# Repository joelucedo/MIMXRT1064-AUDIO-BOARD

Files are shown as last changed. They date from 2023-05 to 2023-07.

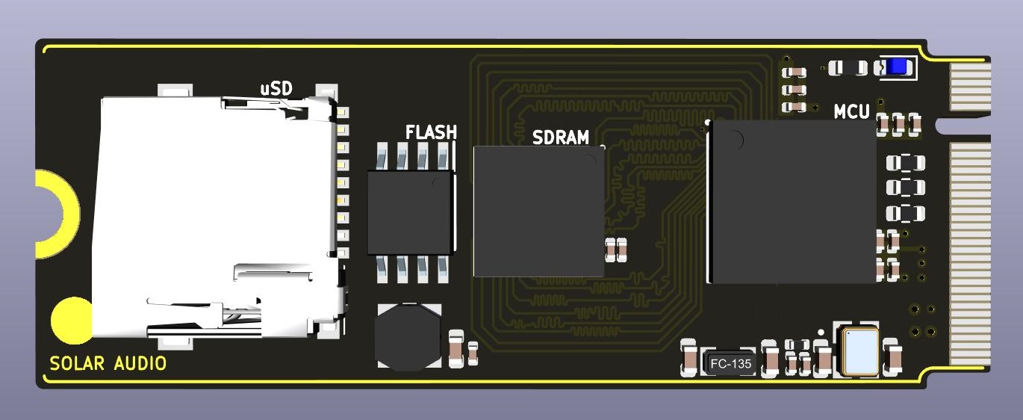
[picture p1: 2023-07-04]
IMAGES/MIMXRT1064 MCU Module.jpg

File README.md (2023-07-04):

# MIMXRT1064 MCU BOARD
MIMXRT1064 MCU Module

## WHAT ?
M7 MCU + SDRAM + FLASH + SD
</br>
## STATUS
Work in progress.
</br>
## SPECS
#### MCU : MIMXRT1064CVL5B 
* ***Cores*** : 1 x ARM Cortex M7 (32KB L1 Cache - FPU)
* ***Clock frequency*** : 528 MHz  
* ***On chip Flash*** : 4MB  
* ***On chip RAM*** : 1MB
* ***USB*** : Two USB 2.0 HS OTG controllers with integrated PHY interfaces
#### SDRAM : IS42S16160J-6BLI
* ***Memory Size*** : 256Mb
* ***Data Bus Width*** : 16 Bit
* ***Maximum clock frequency*** : 166MHz
#### QSPI Flash : IS25WP064A-JBLE
* ***Memory Size*** : 64Mbit
* ***Data Bus Width*** : 8 Bit
* ***Maximum clock frequency*** : 133MHz
#### SD Memory Card Socket
* ***Capacity*** : Up to 2TB SDHX card
* ***Data transfer rate*** : Up to 104 MB/s (UHS-I SDR104)

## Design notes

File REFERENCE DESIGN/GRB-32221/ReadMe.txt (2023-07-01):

README for GRB-32221_A1.zip

Company Part Number: 170-32221 REV A1

Date: Mon, 11 Mar 2019 02:16:21 GMT

NXP Semiconductors
6501 William Cannon Drive West
Austin, TX 78735-8598

CAD Engineer
============
Company Contact     : [full_name]
Work Phone          : 512-895-XXXX
Email               : [email]@nxp.com

CAD Manager
===========
Company Contact     : Daniel Kruczek
Work Phone          : 512-895-6081
Email               : daniel.kruczek@nxp.com

Manufacturing Program Manager
=============================
Company Contact     : [full_name]
Work Phone          : 512-895-XXXX
Email               : [email]@nxp.com

Product Engineer
================
Company Contact     : [full_name]
Work Phone          : 512-895-XXXX
Email               : [email]@nxp.com

Design for Manufacturing Engineer
=================================
Company Contact     : Andres Marquez
Work Phone          : +52(33) 3283-2100 x3068
Email               : andres.marquez@nxp.com

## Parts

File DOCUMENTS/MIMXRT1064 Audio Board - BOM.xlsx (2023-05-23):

MIMXRT1064 MCU Module - BOM
Ref | Description | Package/Mounting | Value | Quantity | Manufacturer | Manufacturer PN | Supplier | Supplier PN | Cost/Unit | Cost/Units | Stock | Basic/Extended | Notes
RESISTORS
 | SMD Chip Resistor - 10k - 62.5mW - ±1% - 0402 | 0402 | 10k |  | UNI-ROYAL | 0402WGF1002TCE | JLCPCB | C25744 | $0.0006 |  | 7272300 | Basic
 | SMD Chip Resistor - 30k - 62.5mW - ±1% - 0402 | 0402 | 30k |  | YAGEO | AF0402FR-0730KL | JLCPCB | C144036 | $0.004 |  | 9800 | Extended
 | SMD Chip Resistor - 2,2M - 62.5mW - ±1% - 0402 | 0402 | 2,2M |  | UNI-ROYAL | 0402WGJ0225TCE | JLCPCB | C26089 | $0.0005 |  | 10394 | Extended
CAPACITORS
 | SMD MLCC - 8pF - 50V - C0G - 0.5pF - 0402 | 0402 | 8pF |  | Murata Electronics | GCM1555C1H8R0DA16D | JLCPCB | C126517 | $0.0082 |  | 10225 | Extended
 | SMD MLCC - 12pF - 50V - C0G - ±2% - 0402 | 0402 | 12pF |  | Murata Electronics | GRM1555C1H120GA01D | JLCPCB | C161527 | $0.0092 |  | 6768 | Extended
 | SMD MLCC - 100nF - 50V - X7R - ±10% - 0402 | 0402 | 100nF |  | Samsung Electro-Mechanics | CL05B104KB54PNC | JLCPCB | C307331 | $0.0068 |  | 1466168 | Basic
 | SMD MLCC - 220nF - 16V - X7R - ±10% - 0402 | 0402 | 0.22uF |  | Samsung Electro-Mechanics | CL05B224KO5NNNC | JLCPCB | C16772 | $0.0051 |  | 120532 | Basic
 | SMD MLCC - 1uF - 25V - X5R - ±10% - 0402 | 0402 | 1uF |  | Samsung Electro-Mechanics | CL05A105KA5NQNC | JLCPCB | C52923 | $0.0039 |  | 1161993 | Basic
 | SMD MLCC - 4.7uF - 10V - X5R - ±20% - 0402 | 0402 | 4.7uF |  | Samsung Electro-Mechanics | CL05A475MP5NRNC | JLCPCB | C23733 | $0.0071 |  | 472642 | Basic
 | SMD MLCC -10uF - 10V - X5R - ±10% - 0603 | 0603 | 10uF |  | Samsung Electro-Mechanics | CL10A106KP8NNNC | JLCPCB | C19702 | $0.0066 |  | 1119998 | Basic
 | SMD MLCC - 22uF - 6.3V - X5R - ±20% -0603 | 0603 | 22uF |  | Samsung Electro-Mechanics | CL10A226MQ8NRNC | JLCPCB | C59461 | $0.0086 |  | 1692113 | Basic
INDUCTORS
 | SMD power inductor - 4.7uH - 800mA - 0R230 -20% - 0805 | 0805 | 4.7uH |  | Murata Electronics | LQM21PN4R7MGRD | JLCPCB | C86090 | $0.0765 |  | 4343 | Extended
FERRITE BEAD
 | SMD Ferrite - 120R - 800mA - 0.180R - 25% - SMD 0603 | 0603 | 120R@100MHz |  | Murata Electronics | BLM18AG121SN1D | JLCPCB | C76892 | $0.0084 |  | 78897 | Extended
INTEGRATED CIRCUITS
 | Microcontrôleurs ARM - MCU i.MXRT1064 | MAPBGA-196 |  |  | NXP Semicon | MIMXRT1064CVL5B | JLCPCB | C2879860 | $11.3056 |  | 942 | Extended
 | DRAM 256M, 3.3V, SDRAM, 16Mx16, 166Mhz, 54 ball BGA (8mmx8mm) | TFBGA-54(8x8) | 256Mbit (32MByte) |  | ISSI | IS42S16160J-6BLI | JLCPCB | C1351289 | $4.3646 |  | 280 | Extended
 | Flash NOR 64Mb QPI/QPI/QSPI, 8-pin SOP 208Mil | SOIC-Wide-8 | 64 Mbit |  | ISSI | IS25WP064A-JBLE | JLCPCB | C190624 | $1.0281 |  | 2304 | Extended
CRYSTALS
 | Crystal - 24MHz - 12pF - 40R - SMD2016-4P | SMD3225-4P | 24MHz |  | TXC Corp | 7V24000026 | JLCPCB | C337205 | $0.1455 |  | 2955 | Extended
 | Crystal - 32.768kHz - 7pF - 70k - ±20ppm - SMD3215-2P | SMD3215-2P | 32.768 MHz |  | Seiko Epson | Q13FC1350000200 | JLCPCB | C48615 | $0.2144 |  | 1441 | Extended
MECHANICALS
 | Deck MicroSD card (TF card) Self bomb SMD SD Card Connectors |  |  |  | SOFNG | TF-15x15 | JLCPCB | C111196 | $0.1986 |  | 4957 | Extended

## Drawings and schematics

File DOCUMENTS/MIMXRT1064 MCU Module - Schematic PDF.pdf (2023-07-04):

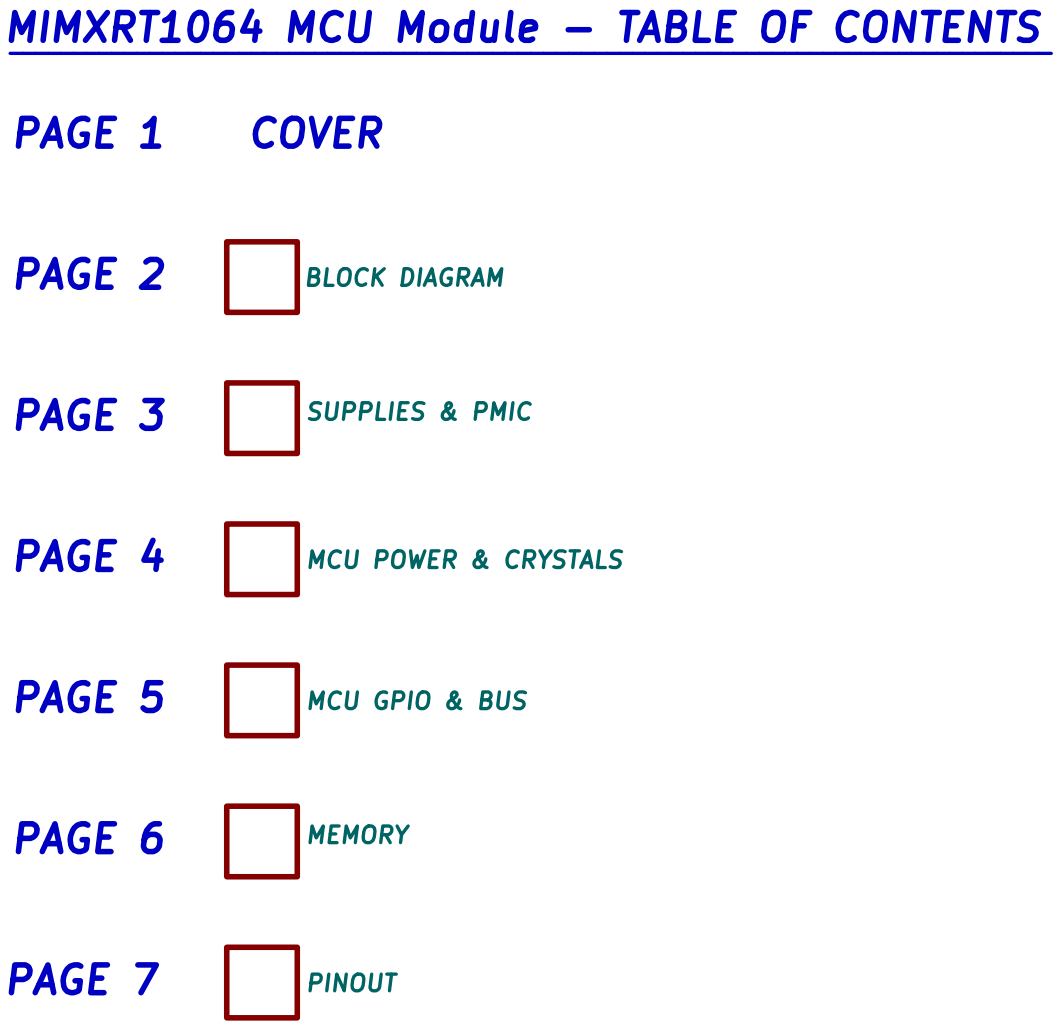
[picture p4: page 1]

MIMXRT1064 MCU Module - TABLE OF CONTENTS
__________________________________________________________________________________ PAGE 6
PAGE 1 COVER

File: MIMXRT1064 MCU Module.kicad_sch Sheet: / þÿJoël Ucedo

Id: 1/7 Title: MIMXRT1064 MCU Module

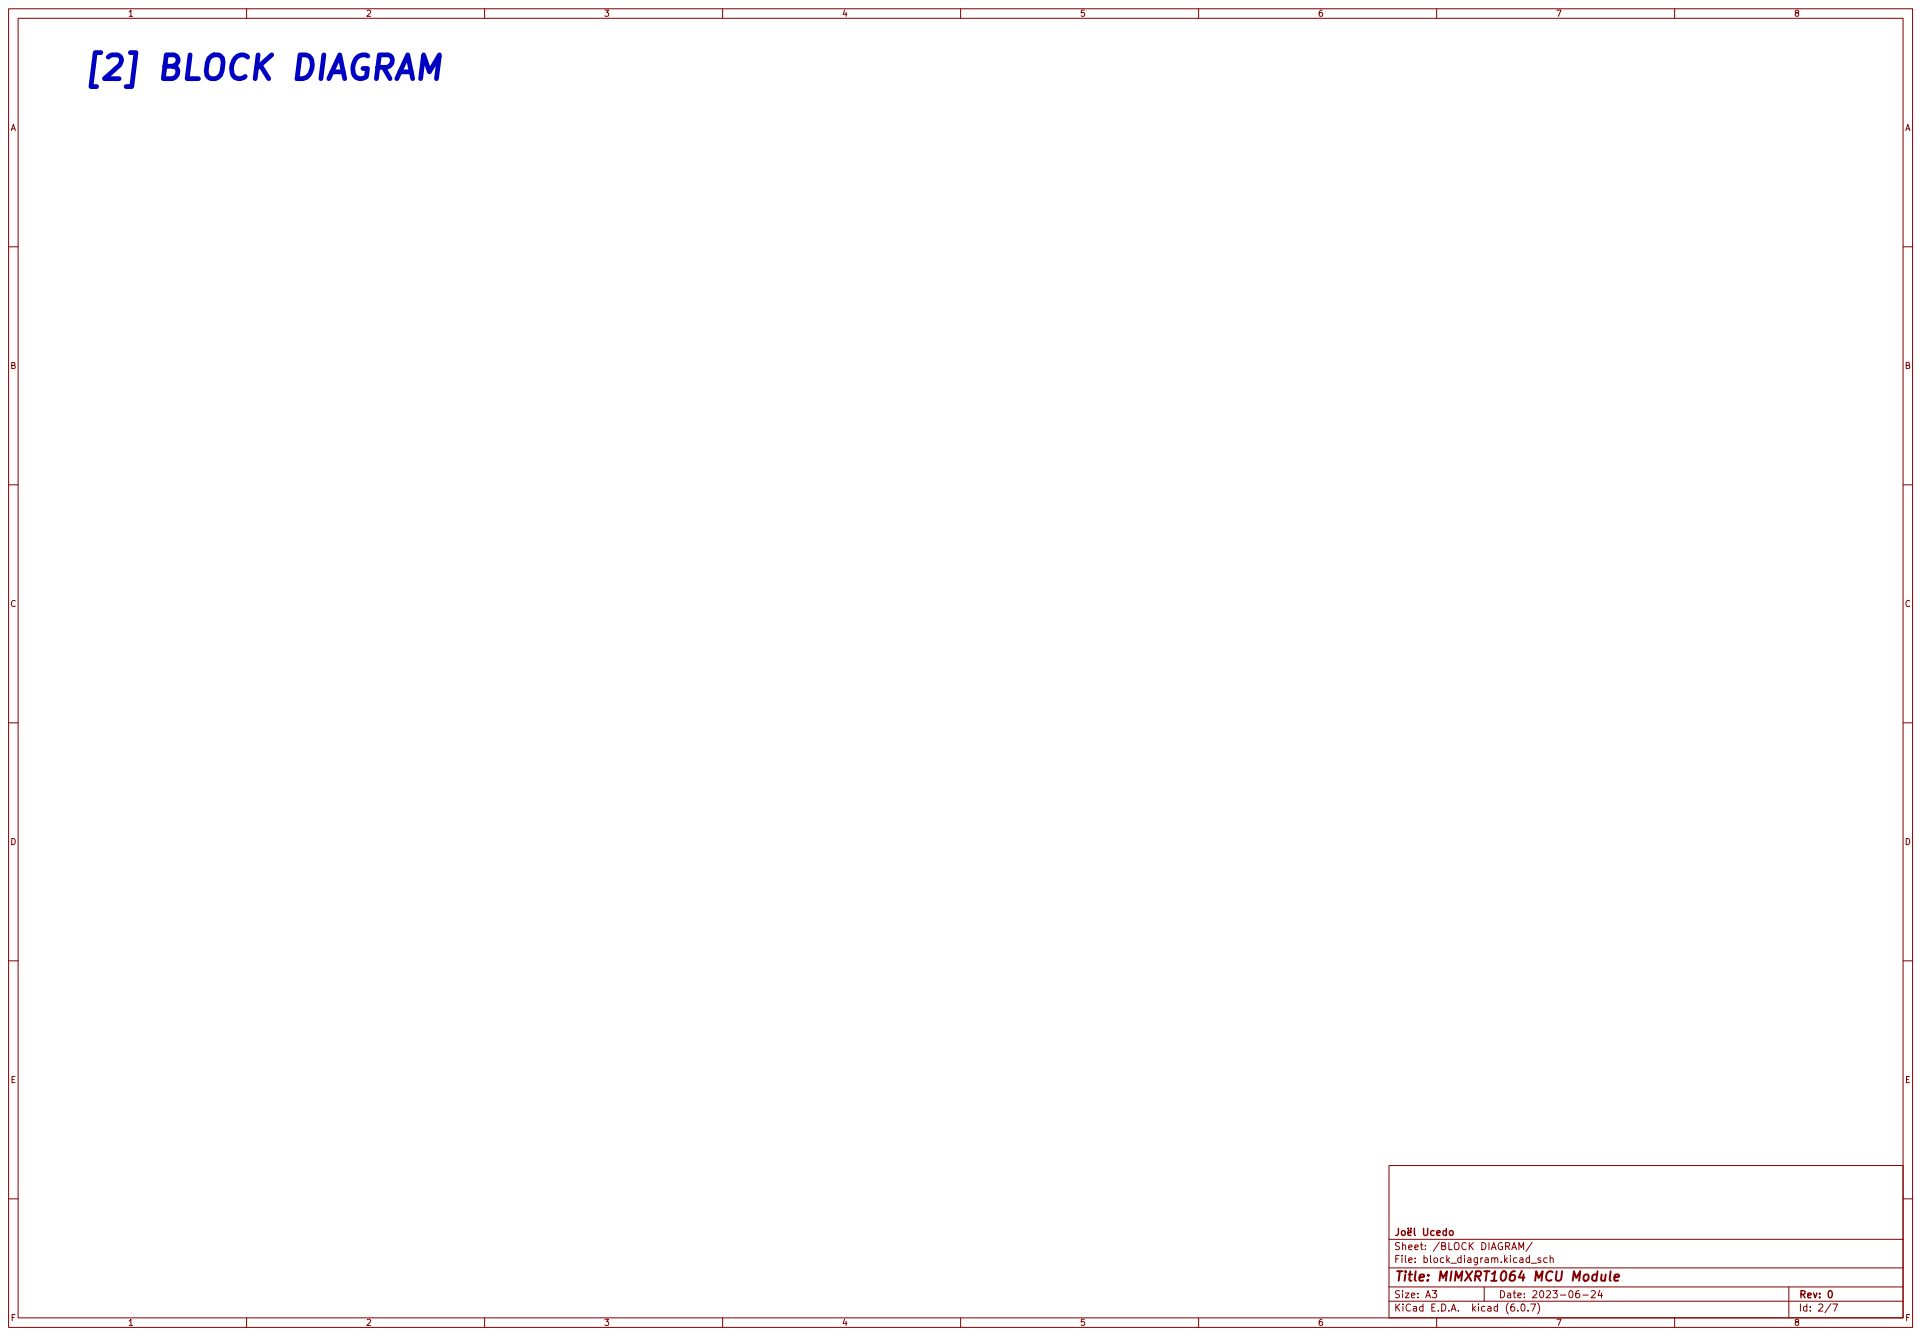
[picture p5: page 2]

File: block_diagram.kicad_sch Sheet: /BLOCK DIAGRAM/ þÿJoël Ucedo

Id: 2/7 Title: MIMXRT1064 MCU Module

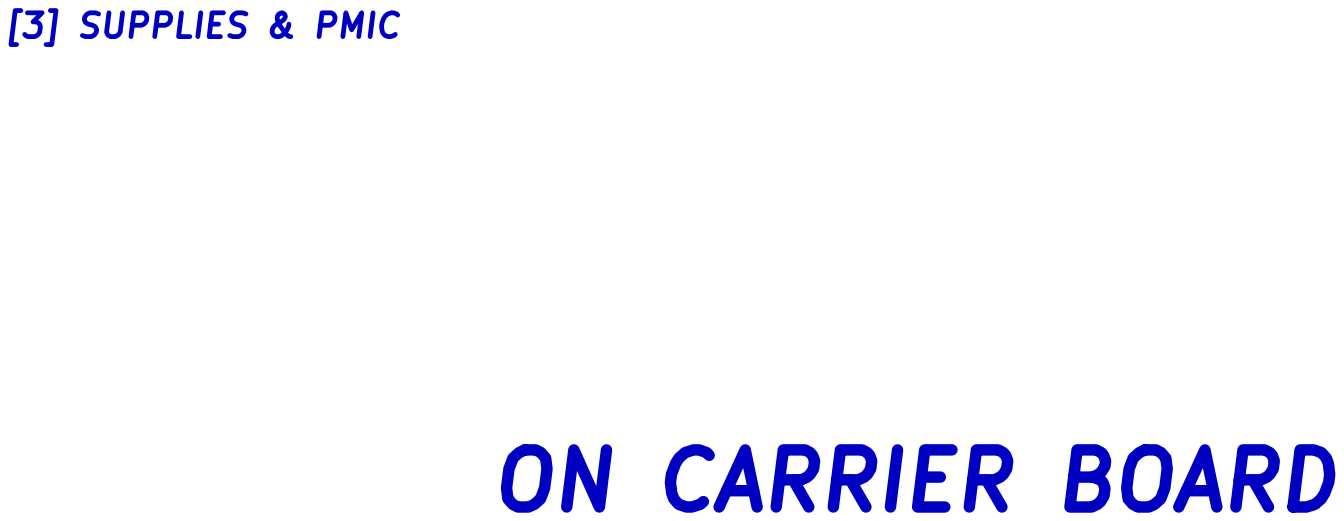
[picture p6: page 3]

File: supplies_pmic.kicad_sch Sheet: /SUPPLIES & PMIC/ þÿJoël Ucedo

Id: 3/7 Title: MIMXRT1064 MCU Module

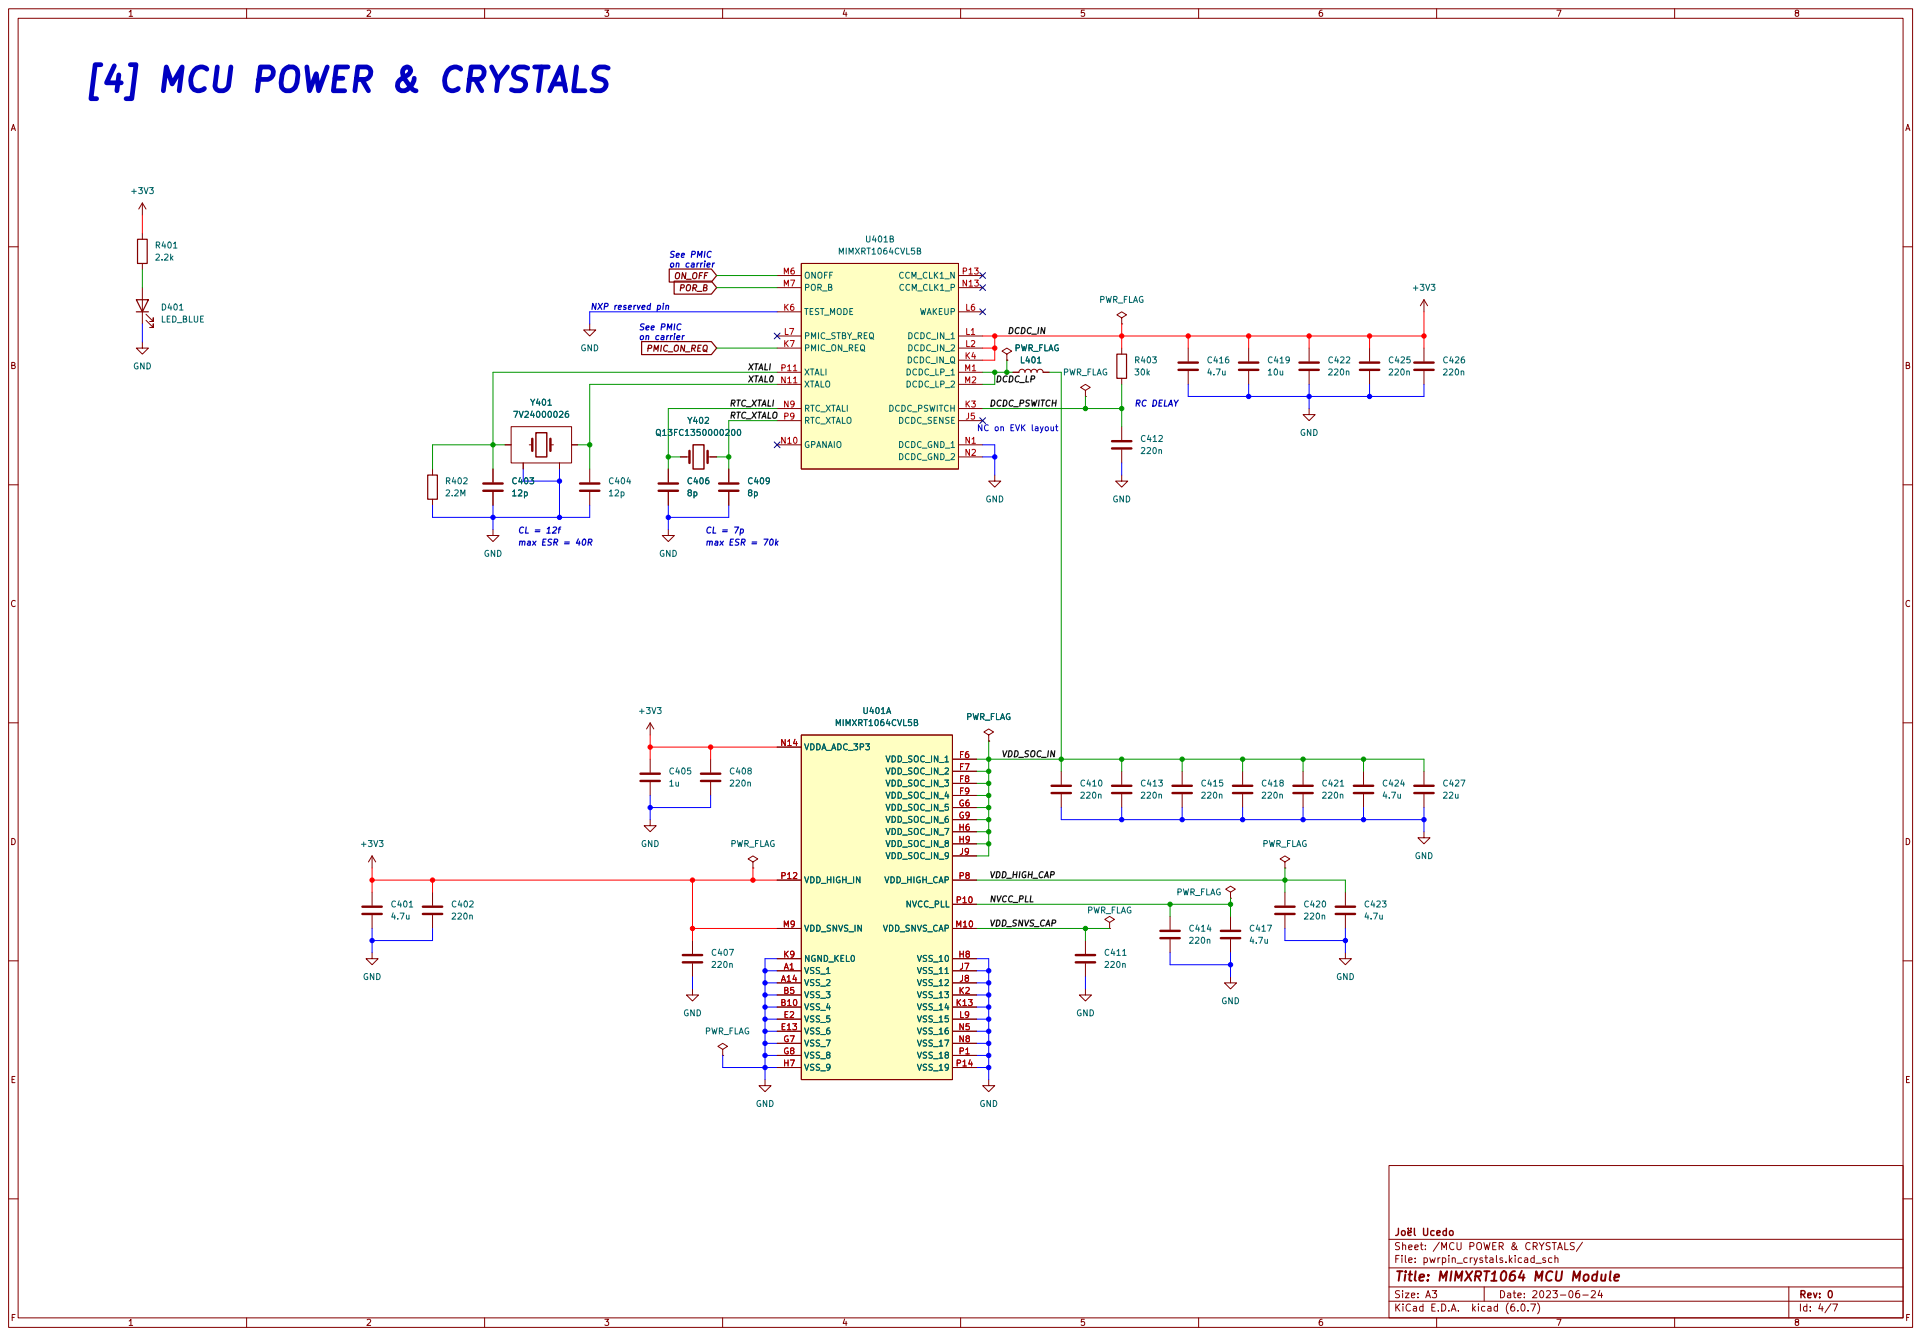
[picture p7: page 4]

on carrier [4] MCU POWER & CRYSTALS

on carrier NXP reserved pin See PMIC

DCDC_LP NVCC_PLL max ESR = 70k CL = 12f max ESR = 40R

NC on EVK layout Y402 Q13FC1350000200 Y401

File: pwrpin_crystals.kicad_sch Sheet: /MCU POWER & CRYSTALS/ þÿJoël Ucedo

Id: 4/7 Title: MIMXRT1064 MCU Module

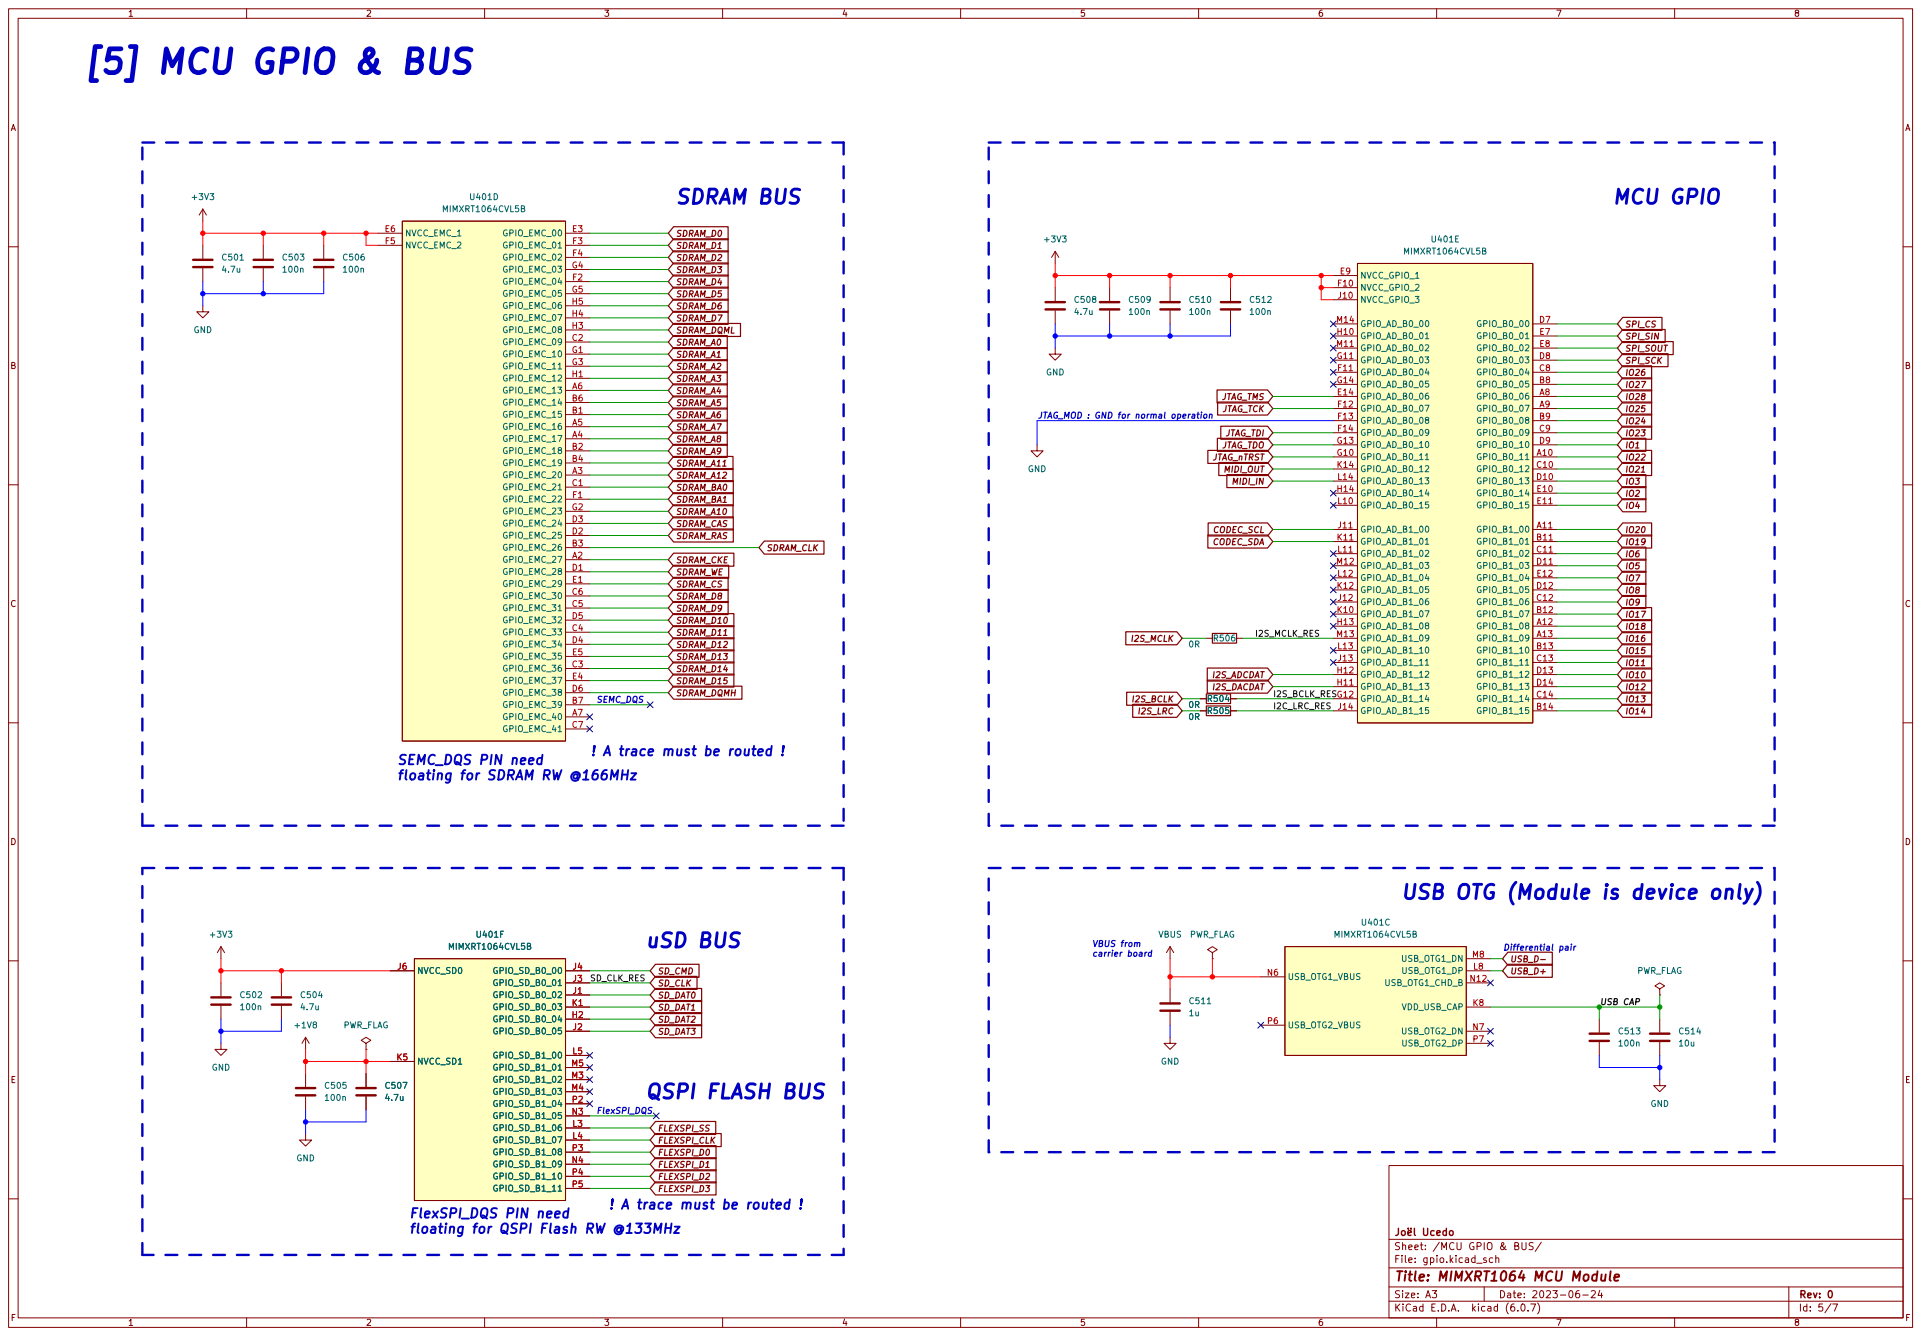
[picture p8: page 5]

JTAG_MOD : GND for normal operation

! A trace must be routed ! SEMC_DQS PIN need
floating for SDRAM RW @166MHz

USB OTG (Module is device only)

! A trace must be routed !

FlexSPI_DQS PIN need
floating for QSPI Flash RW @133MHz

File: gpio.kicad_sch Sheet: /MCU GPIO & BUS/ þÿJoël Ucedo

Id: 5/7 Title: MIMXRT1064 MCU Module

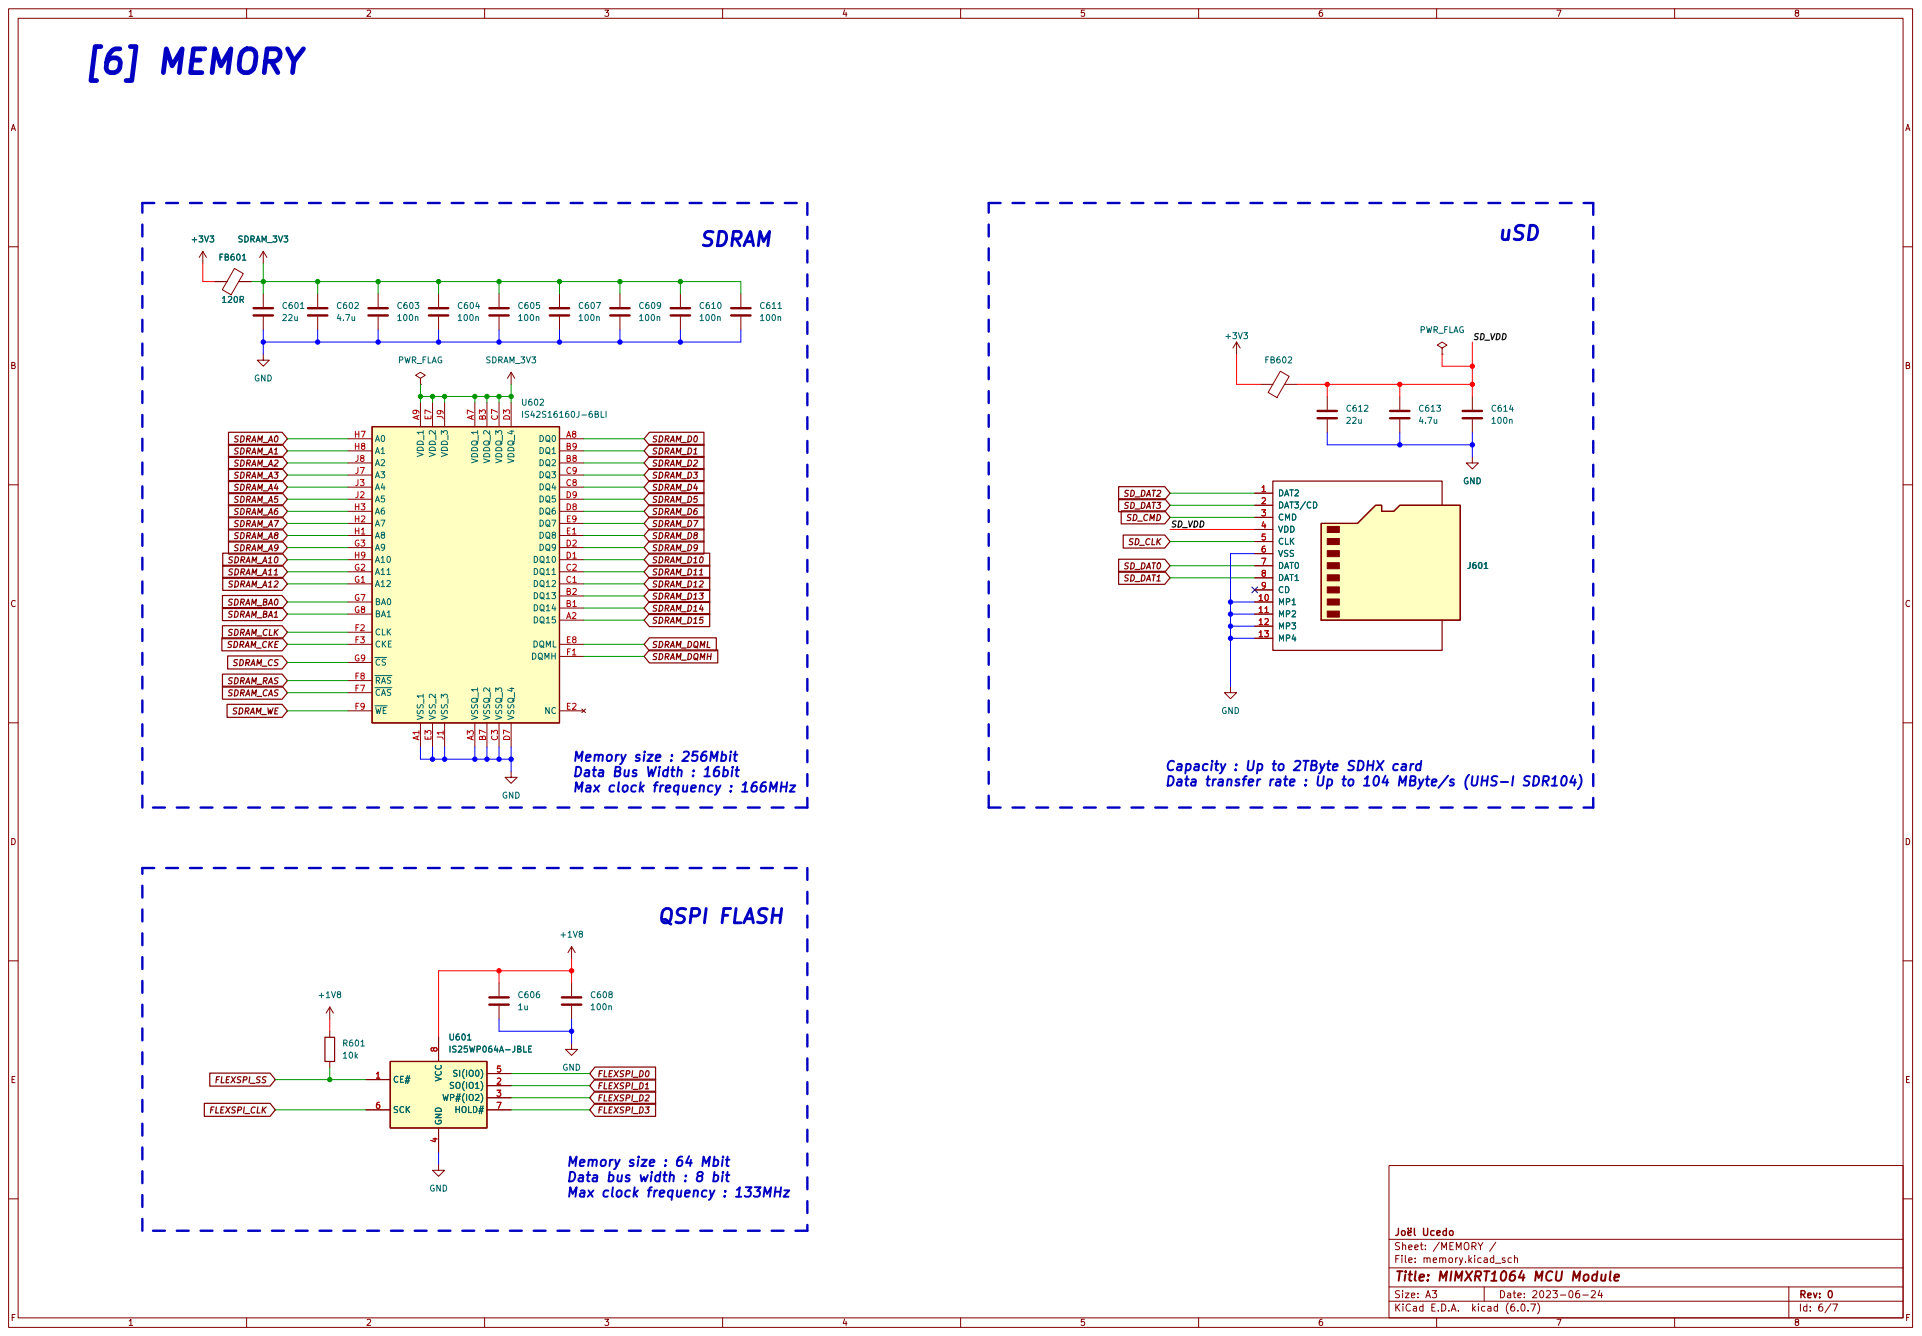
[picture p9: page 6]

Capacity : Up to 2TByte SDHX card
Data transfer rate : Up to 104 MByte/s (UHS-I SDR104)

4 SI(IO0) 5 SCK 6 HOLD# 7 VCC

Memory size : 64 Mbit
Data bus width : 8 bit
Max clock frequency : 133MHz

File: memory.kicad_sch Sheet: /MEMORY / þÿJoël Ucedo

Id: 6/7 Title: MIMXRT1064 MCU Module

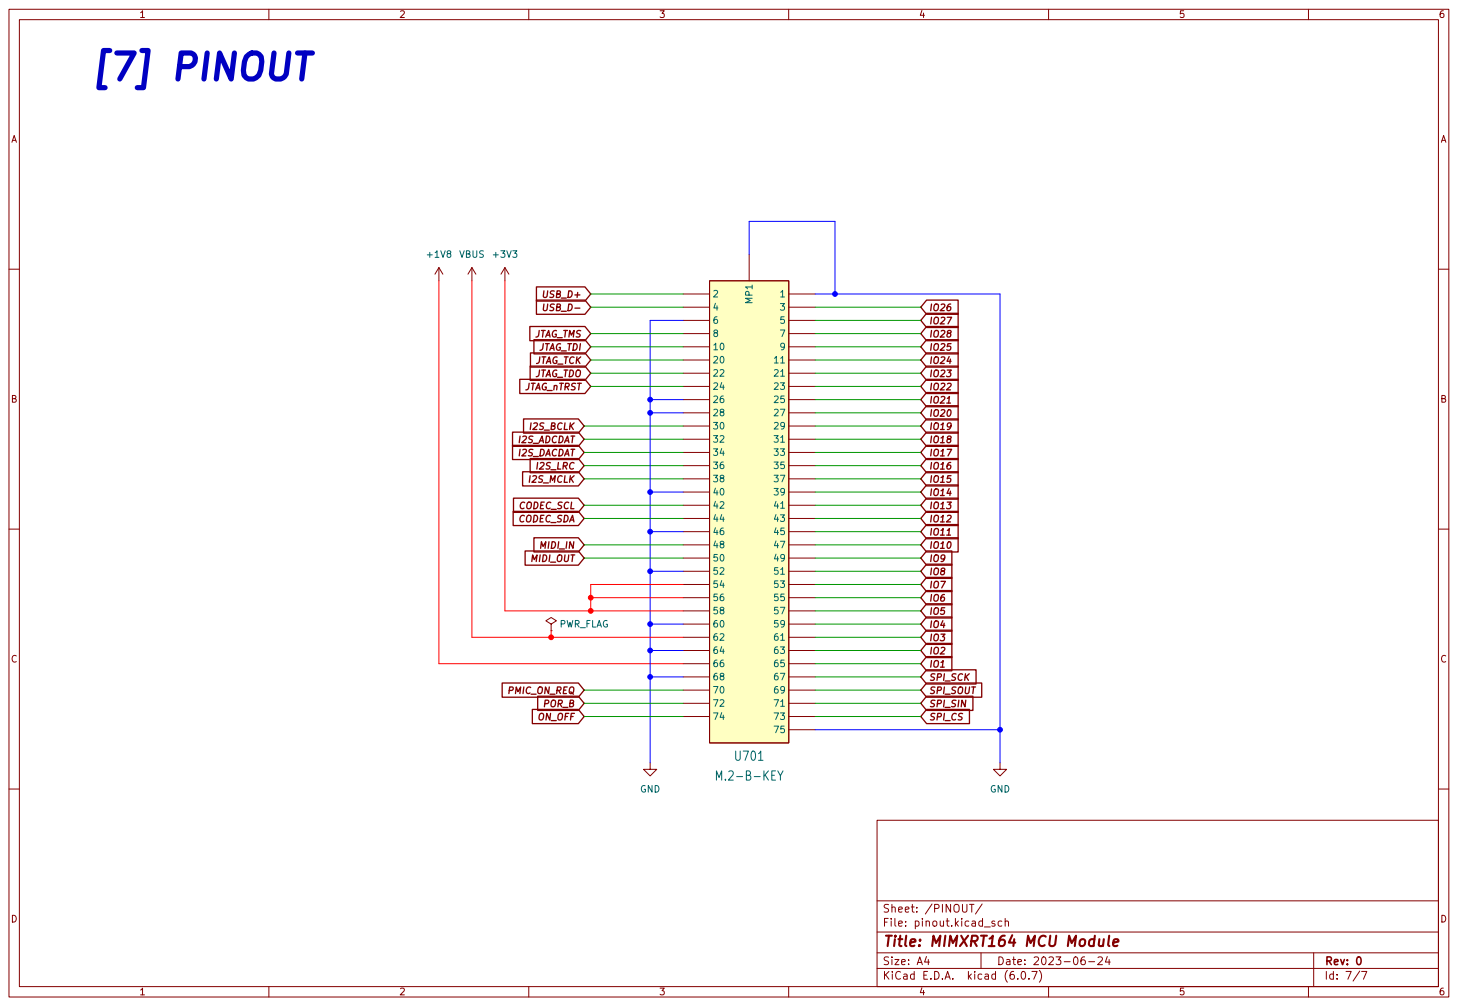
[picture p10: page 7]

File: pinout.kicad_sch Sheet: /PINOUT/
Id: 7/7 Title: MIMXRT164 MCU Module

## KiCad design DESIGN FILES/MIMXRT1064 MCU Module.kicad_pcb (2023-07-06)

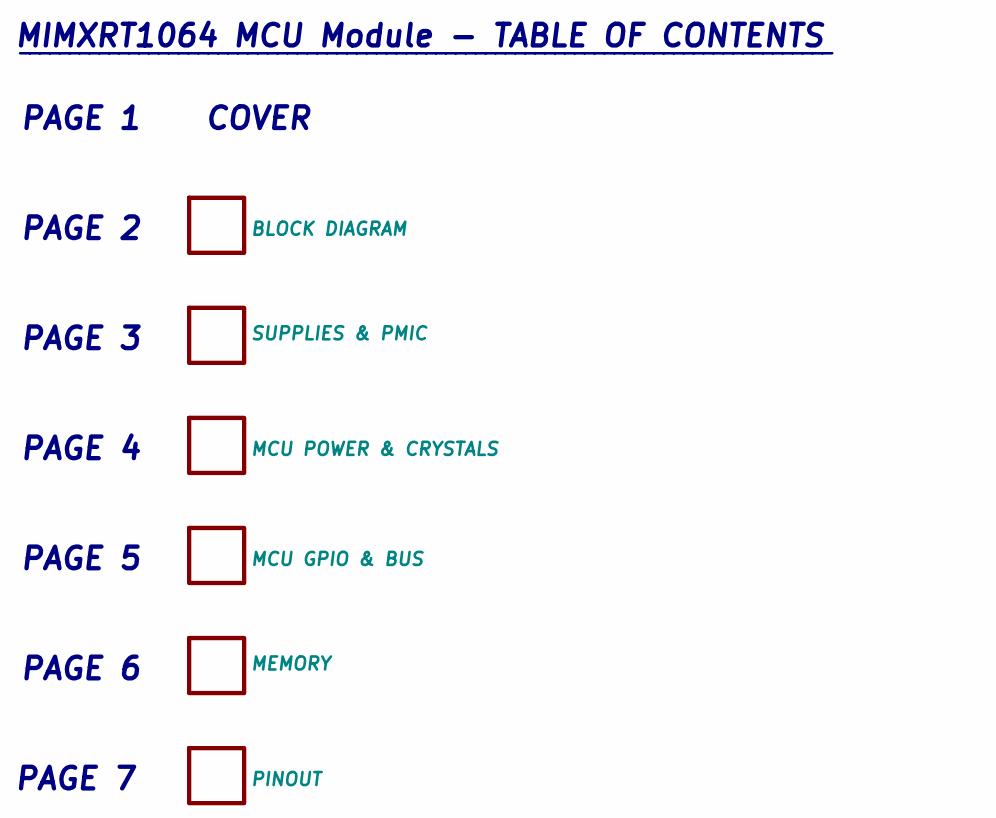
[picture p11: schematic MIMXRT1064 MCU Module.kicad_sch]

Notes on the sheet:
MIMXRT1064 MCU Module - TABLE OF CONTENTS
PAGE 6
PAGE 3
PAGE 4
PAGE 1 COVER
PAGE 2
PAGE 5
__________________________________________________________________________________
PAGE 7

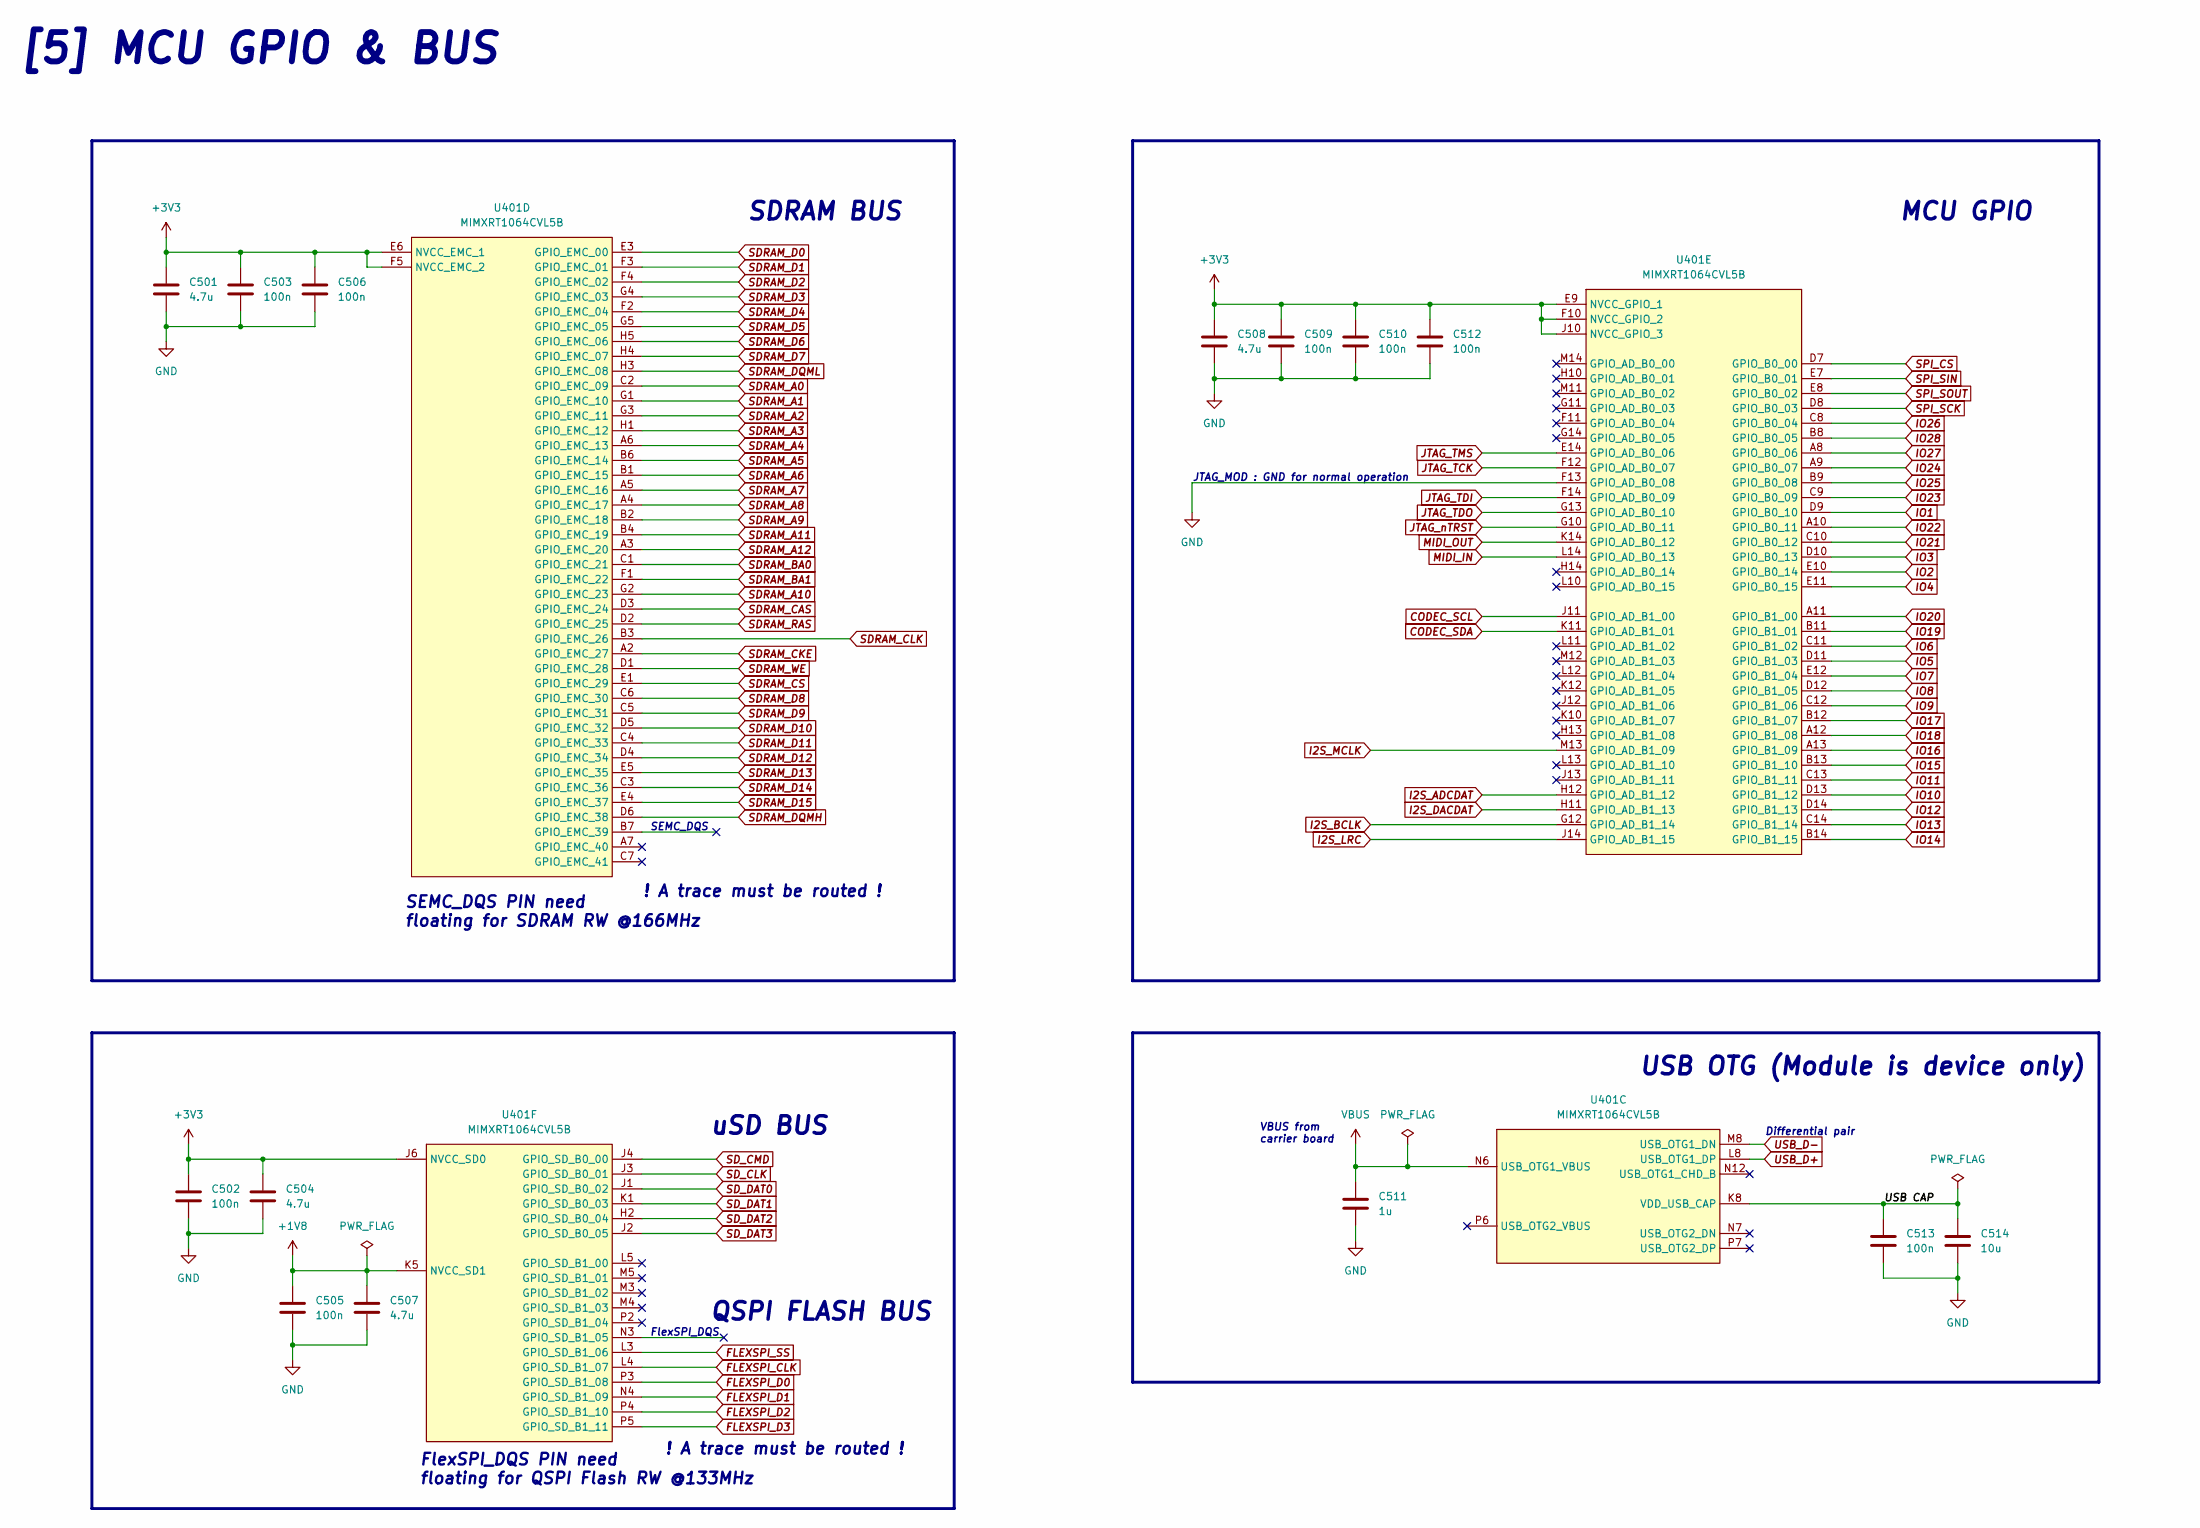
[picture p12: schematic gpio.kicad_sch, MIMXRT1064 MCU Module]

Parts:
C501, C504, C507, C508: 4.7u; 0402_CL05A475MP5NRNC
C502, C503, C505, C506, C509, C510, C512, C513: 100n; 0402_CL05B104KB54PNC
C511: 1u; 0402_CL05A105KA5NQNC
C514: 10u; 0603_CL10A106KP8NNNC
U401: MIMXRT1064CVL5B

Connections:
+1V8: C505.1, C507.1, U401.K5 (NVCC_SD1); also elsewhere on the board
+3V3: C501.1, C502.1, C503.1, C504.1, C506.1, C508.1, C509.1, C510.1, C512.1, U401.E6 (NVCC_EMC_1), U401.E9 (NVCC_GPIO_1), U401.F5 (NVCC_EMC_2), U401.F10 (NVCC_GPIO_2), U401.J6 (NVCC_SD0), U401.J10 (NVCC_GPIO_3); also elsewhere on the board
/MCU GPIO & BUS/USB CAP: C513.1, C514.1, U401.K8 (VDD_USB_CAP)
CODEC_SCL: U401.J11 (GPIO_AD_B1_00); also elsewhere on the board
CODEC_SDA: U401.K11 (GPIO_AD_B1_01); also elsewhere on the board
FLEXSPI_CLK: U401.L4 (GPIO_SD_B1_07); also elsewhere on the board
FLEXSPI_D0: U401.P3 (GPIO_SD_B1_08); also elsewhere on the board
FLEXSPI_D1: U401.N4 (GPIO_SD_B1_09); also elsewhere on the board
FLEXSPI_D2: U401.P4 (GPIO_SD_B1_10); also elsewhere on the board
FLEXSPI_D3: U401.P5 (GPIO_SD_B1_11); also elsewhere on the board
FLEXSPI_SS: U401.L3 (GPIO_SD_B1_06); also elsewhere on the board
GND: C501.2, C502.2, C503.2, C504.2, C505.2, C506.2, C507.2, C508.2, C509.2, C510.2, C511.2, C512.2, C513.2, C514.2, U401.F13 (GPIO_AD_B0_08); also elsewhere on the board
I2S_ADCDAT: U401.H12 (GPIO_AD_B1_12); also elsewhere on the board
I2S_BCLK: U401.G12 (GPIO_AD_B1_14); also elsewhere on the board
I2S_DACDAT: U401.H11 (GPIO_AD_B1_13); also elsewhere on the board
I2S_LRC: U401.J14 (GPIO_AD_B1_15); also elsewhere on the board
I2S_MCLK: U401.M13 (GPIO_AD_B1_09); also elsewhere on the board
IO1: U401.D9 (GPIO_B0_10); also elsewhere on the board
IO2: U401.E10 (GPIO_B0_14); also elsewhere on the board
IO3: U401.D10 (GPIO_B0_13); also elsewhere on the board
IO4: U401.E11 (GPIO_B0_15); also elsewhere on the board
IO5: U401.D11 (GPIO_B1_03); also elsewhere on the board
IO6: U401.C11 (GPIO_B1_02); also elsewhere on the board
IO7: U401.E12 (GPIO_B1_04); also elsewhere on the board
IO8: U401.D12 (GPIO_B1_05); also elsewhere on the board
IO9: U401.C12 (GPIO_B1_06); also elsewhere on the board
IO10: U401.D13 (GPIO_B1_12); also elsewhere on the board
IO11: U401.C13 (GPIO_B1_11); also elsewhere on the board
IO12: U401.D14 (GPIO_B1_13); also elsewhere on the board
IO13: U401.C14 (GPIO_B1_14); also elsewhere on the board
IO14: U401.B14 (GPIO_B1_15); also elsewhere on the board
IO15: U401.B13 (GPIO_B1_10); also elsewhere on the board
IO16: U401.A13 (GPIO_B1_09); also elsewhere on the board
IO17: U401.B12 (GPIO_B1_07); also elsewhere on the board
IO18: U401.A12 (GPIO_B1_08); also elsewhere on the board
IO19: U401.B11 (GPIO_B1_01); also elsewhere on the board
IO20: U401.A11 (GPIO_B1_00); also elsewhere on the board
IO21: U401.C10 (GPIO_B0_12); also elsewhere on the board
IO22: U401.A10 (GPIO_B0_11); also elsewhere on the board
IO23: U401.C9 (GPIO_B0_09); also elsewhere on the board
IO24: U401.A9 (GPIO_B0_07); also elsewhere on the board
IO25: U401.B9 (GPIO_B0_08); also elsewhere on the board
IO26: U401.C8 (GPIO_B0_04); also elsewhere on the board
IO27: U401.A8 (GPIO_B0_06); also elsewhere on the board
IO28: U401.B8 (GPIO_B0_05); also elsewhere on the board
JTAG_TCK: U401.F12 (GPIO_AD_B0_07); also elsewhere on the board
JTAG_TDI: U401.F14 (GPIO_AD_B0_09); also elsewhere on the board
JTAG_TDO: U401.G13 (GPIO_AD_B0_10); also elsewhere on the board
JTAG_TMS: U401.E14 (GPIO_AD_B0_06); also elsewhere on the board
JTAG_nTRST: U401.G10 (GPIO_AD_B0_11); also elsewhere on the board
MIDI_IN: U401.L14 (GPIO_AD_B0_13); also elsewhere on the board
MIDI_OUT: U401.K14 (GPIO_AD_B0_12); also elsewhere on the board
SDRAM_A0: U401.C2 (GPIO_EMC_09); also elsewhere on the board
SDRAM_A1: U401.G1 (GPIO_EMC_10); also elsewhere on the board
SDRAM_A2: U401.G3 (GPIO_EMC_11); also elsewhere on the board
SDRAM_A3: U401.H1 (GPIO_EMC_12); also elsewhere on the board
SDRAM_A4: U401.A6 (GPIO_EMC_13); also elsewhere on the board
SDRAM_A5: U401.B6 (GPIO_EMC_14); also elsewhere on the board
SDRAM_A6: U401.B1 (GPIO_EMC_15); also elsewhere on the board
SDRAM_A7: U401.A5 (GPIO_EMC_16); also elsewhere on the board
SDRAM_A8: U401.A4 (GPIO_EMC_17); also elsewhere on the board
SDRAM_A9: U401.B2 (GPIO_EMC_18); also elsewhere on the board
SDRAM_A10: U401.G2 (GPIO_EMC_23); also elsewhere on the board
SDRAM_A11: U401.B4 (GPIO_EMC_19); also elsewhere on the board
SDRAM_A12: U401.A3 (GPIO_EMC_20); also elsewhere on the board
SDRAM_BA0: U401.C1 (GPIO_EMC_21); also elsewhere on the board
SDRAM_BA1: U401.F1 (GPIO_EMC_22); also elsewhere on the board
SDRAM_CAS: U401.D3 (GPIO_EMC_24); also elsewhere on the board
SDRAM_CKE: U401.A2 (GPIO_EMC_27); also elsewhere on the board
SDRAM_CLK: U401.B3 (GPIO_EMC_26); also elsewhere on the board
SDRAM_CS: U401.E1 (GPIO_EMC_29); also elsewhere on the board
SDRAM_D0: U401.E3 (GPIO_EMC_00); also elsewhere on the board
SDRAM_D1: U401.F3 (GPIO_EMC_01); also elsewhere on the board
SDRAM_D2: U401.F4 (GPIO_EMC_02); also elsewhere on the board
SDRAM_D3: U401.G4 (GPIO_EMC_03); also elsewhere on the board
SDRAM_D4: U401.F2 (GPIO_EMC_04); also elsewhere on the board
SDRAM_D5: U401.G5 (GPIO_EMC_05); also elsewhere on the board
SDRAM_D6: U401.H5 (GPIO_EMC_06); also elsewhere on the board
SDRAM_D7: U401.H4 (GPIO_EMC_07); also elsewhere on the board
SDRAM_D8: U401.C6 (GPIO_EMC_30); also elsewhere on the board
SDRAM_D9: U401.C5 (GPIO_EMC_31); also elsewhere on the board
SDRAM_D10: U401.D5 (GPIO_EMC_32); also elsewhere on the board
SDRAM_D11: U401.C4 (GPIO_EMC_33); also elsewhere on the board
SDRAM_D12: U401.D4 (GPIO_EMC_34); also elsewhere on the board
SDRAM_D13: U401.E5 (GPIO_EMC_35); also elsewhere on the board
SDRAM_D14: U401.C3 (GPIO_EMC_36); also elsewhere on the board
SDRAM_D15: U401.E4 (GPIO_EMC_37); also elsewhere on the board
SDRAM_DQMH: U401.D6 (GPIO_EMC_38); also elsewhere on the board
SDRAM_DQML: U401.H3 (GPIO_EMC_08); also elsewhere on the board
SDRAM_RAS: U401.D2 (GPIO_EMC_25); also elsewhere on the board
SDRAM_WE: U401.D1 (GPIO_EMC_28); also elsewhere on the board
SD_CLK: U401.J3 (GPIO_SD_B0_01); also elsewhere on the board
SD_CMD: U401.J4 (GPIO_SD_B0_00); also elsewhere on the board
SD_DAT0: U401.J1 (GPIO_SD_B0_02); also elsewhere on the board
SD_DAT1: U401.K1 (GPIO_SD_B0_03); also elsewhere on the board
SD_DAT2: U401.H2 (GPIO_SD_B0_04); also elsewhere on the board
SD_DAT3: U401.J2 (GPIO_SD_B0_05); also elsewhere on the board
SPI_CS: U401.D7 (GPIO_B0_00); also elsewhere on the board
SPI_SCK: U401.D8 (GPIO_B0_03); also elsewhere on the board
SPI_SIN: U401.E7 (GPIO_B0_01); also elsewhere on the board
SPI_SOUT: U401.E8 (GPIO_B0_02); also elsewhere on the board
USB_D+: U401.L8 (USB_OTG1_DP); also elsewhere on the board
USB_D-: U401.M8 (USB_OTG1_DN); also elsewhere on the board
VBUS: C511.1, U401.N6 (USB_OTG1_VBUS); also elsewhere on the board

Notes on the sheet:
QSPI FLASH BUS
uSD BUS
SDRAM BUS
Differential pair
USB OTG (Module is device only)
FlexSPI_DQS
[5] MCU GPIO & BUS
VBUS from carrier board
SEMC_DQS
MCU GPIO
! A trace must be routed !
FlexSPI_DQS PIN need floating for QSPI Flash RW @133MHz
SEMC_DQS PIN need floating for SDRAM RW @166MHz
JTAG_MOD : GND for normal operation

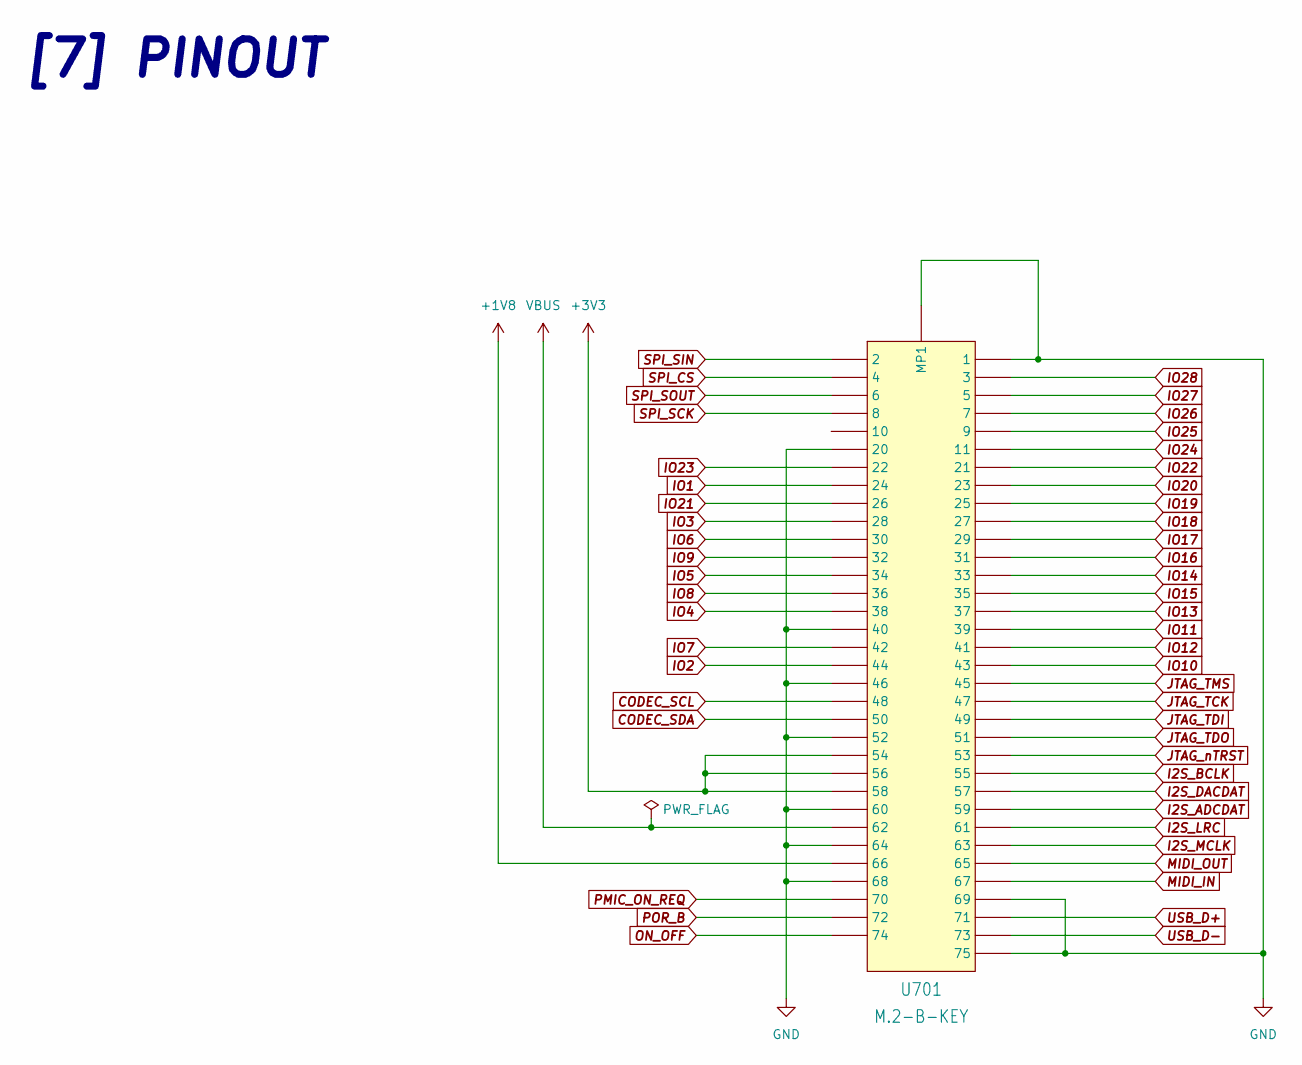
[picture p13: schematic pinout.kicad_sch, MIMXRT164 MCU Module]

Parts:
U701: M.2-B-KEY

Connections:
+1V8: U701.P$66 (66); also elsewhere on the board
+3V3: U701.P$54 (54), U701.P$56 (56), U701.P$58 (58); also elsewhere on the board
CODEC_SCL: U701.P$48 (48); also elsewhere on the board
CODEC_SDA: U701.P$50 (50); also elsewhere on the board
GND: U701.MOUNTING-HOLE (MP1), U701.P$1 (1), U701.P$20 (20), U701.P$40 (40), U701.P$46 (46), U701.P$52 (52), U701.P$60 (60), U701.P$64 (64), U701.P$68 (68), U701.P$69 (69), U701.P$75 (75); also elsewhere on the board
I2S_ADCDAT: U701.P$59 (59); also elsewhere on the board
I2S_BCLK: U701.P$55 (55); also elsewhere on the board
I2S_DACDAT: U701.P$57 (57); also elsewhere on the board
I2S_LRC: U701.P$61 (61); also elsewhere on the board
I2S_MCLK: U701.P$63 (63); also elsewhere on the board
IO1: U701.P$24 (24); also elsewhere on the board
IO2: U701.P$44 (44); also elsewhere on the board
IO3: U701.P$28 (28); also elsewhere on the board
IO4: U701.P$38 (38); also elsewhere on the board
IO5: U701.P$34 (34); also elsewhere on the board
IO6: U701.P$30 (30); also elsewhere on the board
IO7: U701.P$42 (42); also elsewhere on the board
IO8: U701.P$36 (36); also elsewhere on the board
IO9: U701.P$32 (32); also elsewhere on the board
IO10: U701.P$43 (43); also elsewhere on the board
IO11: U701.P$39 (39); also elsewhere on the board
IO12: U701.P$41 (41); also elsewhere on the board
IO13: U701.P$37 (37); also elsewhere on the board
IO14: U701.P$33 (33); also elsewhere on the board
IO15: U701.P$35 (35); also elsewhere on the board
IO16: U701.P$31 (31); also elsewhere on the board
IO17: U701.P$29 (29); also elsewhere on the board
IO18: U701.P$27 (27); also elsewhere on the board
IO19: U701.P$25 (25); also elsewhere on the board
IO20: U701.P$23 (23); also elsewhere on the board
IO21: U701.P$26 (26); also elsewhere on the board
IO22: U701.P$21 (21); also elsewhere on the board
IO23: U701.P$22 (22); also elsewhere on the board
IO24: U701.P$11 (11); also elsewhere on the board
IO25: U701.P$9 (9); also elsewhere on the board
IO26: U701.P$7 (7); also elsewhere on the board
IO27: U701.P$5 (5); also elsewhere on the board
IO28: U701.P$3 (3); also elsewhere on the board
JTAG_TCK: U701.P$47 (47); also elsewhere on the board
JTAG_TDI: U701.P$49 (49); also elsewhere on the board
JTAG_TDO: U701.P$51 (51); also elsewhere on the board
JTAG_TMS: U701.P$45 (45); also elsewhere on the board
JTAG_nTRST: U701.P$53 (53); also elsewhere on the board
MIDI_IN: U701.P$67 (67); also elsewhere on the board
MIDI_OUT: U701.P$65 (65); also elsewhere on the board
ON_OFF: U701.P$74 (74); also elsewhere on the board
PMIC_ON_REQ: U701.P$70 (70); also elsewhere on the board
POR_B: U701.P$72 (72); also elsewhere on the board
SPI_CS: U701.P$4 (4); also elsewhere on the board
SPI_SCK: U701.P$8 (8); also elsewhere on the board
SPI_SIN: U701.P$2 (2); also elsewhere on the board
SPI_SOUT: U701.P$6 (6); also elsewhere on the board
USB_D+: U701.P$71 (71); also elsewhere on the board
USB_D-: U701.P$73 (73); also elsewhere on the board
VBUS: U701.P$62 (62); also elsewhere on the board

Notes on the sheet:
[7] PINOUT

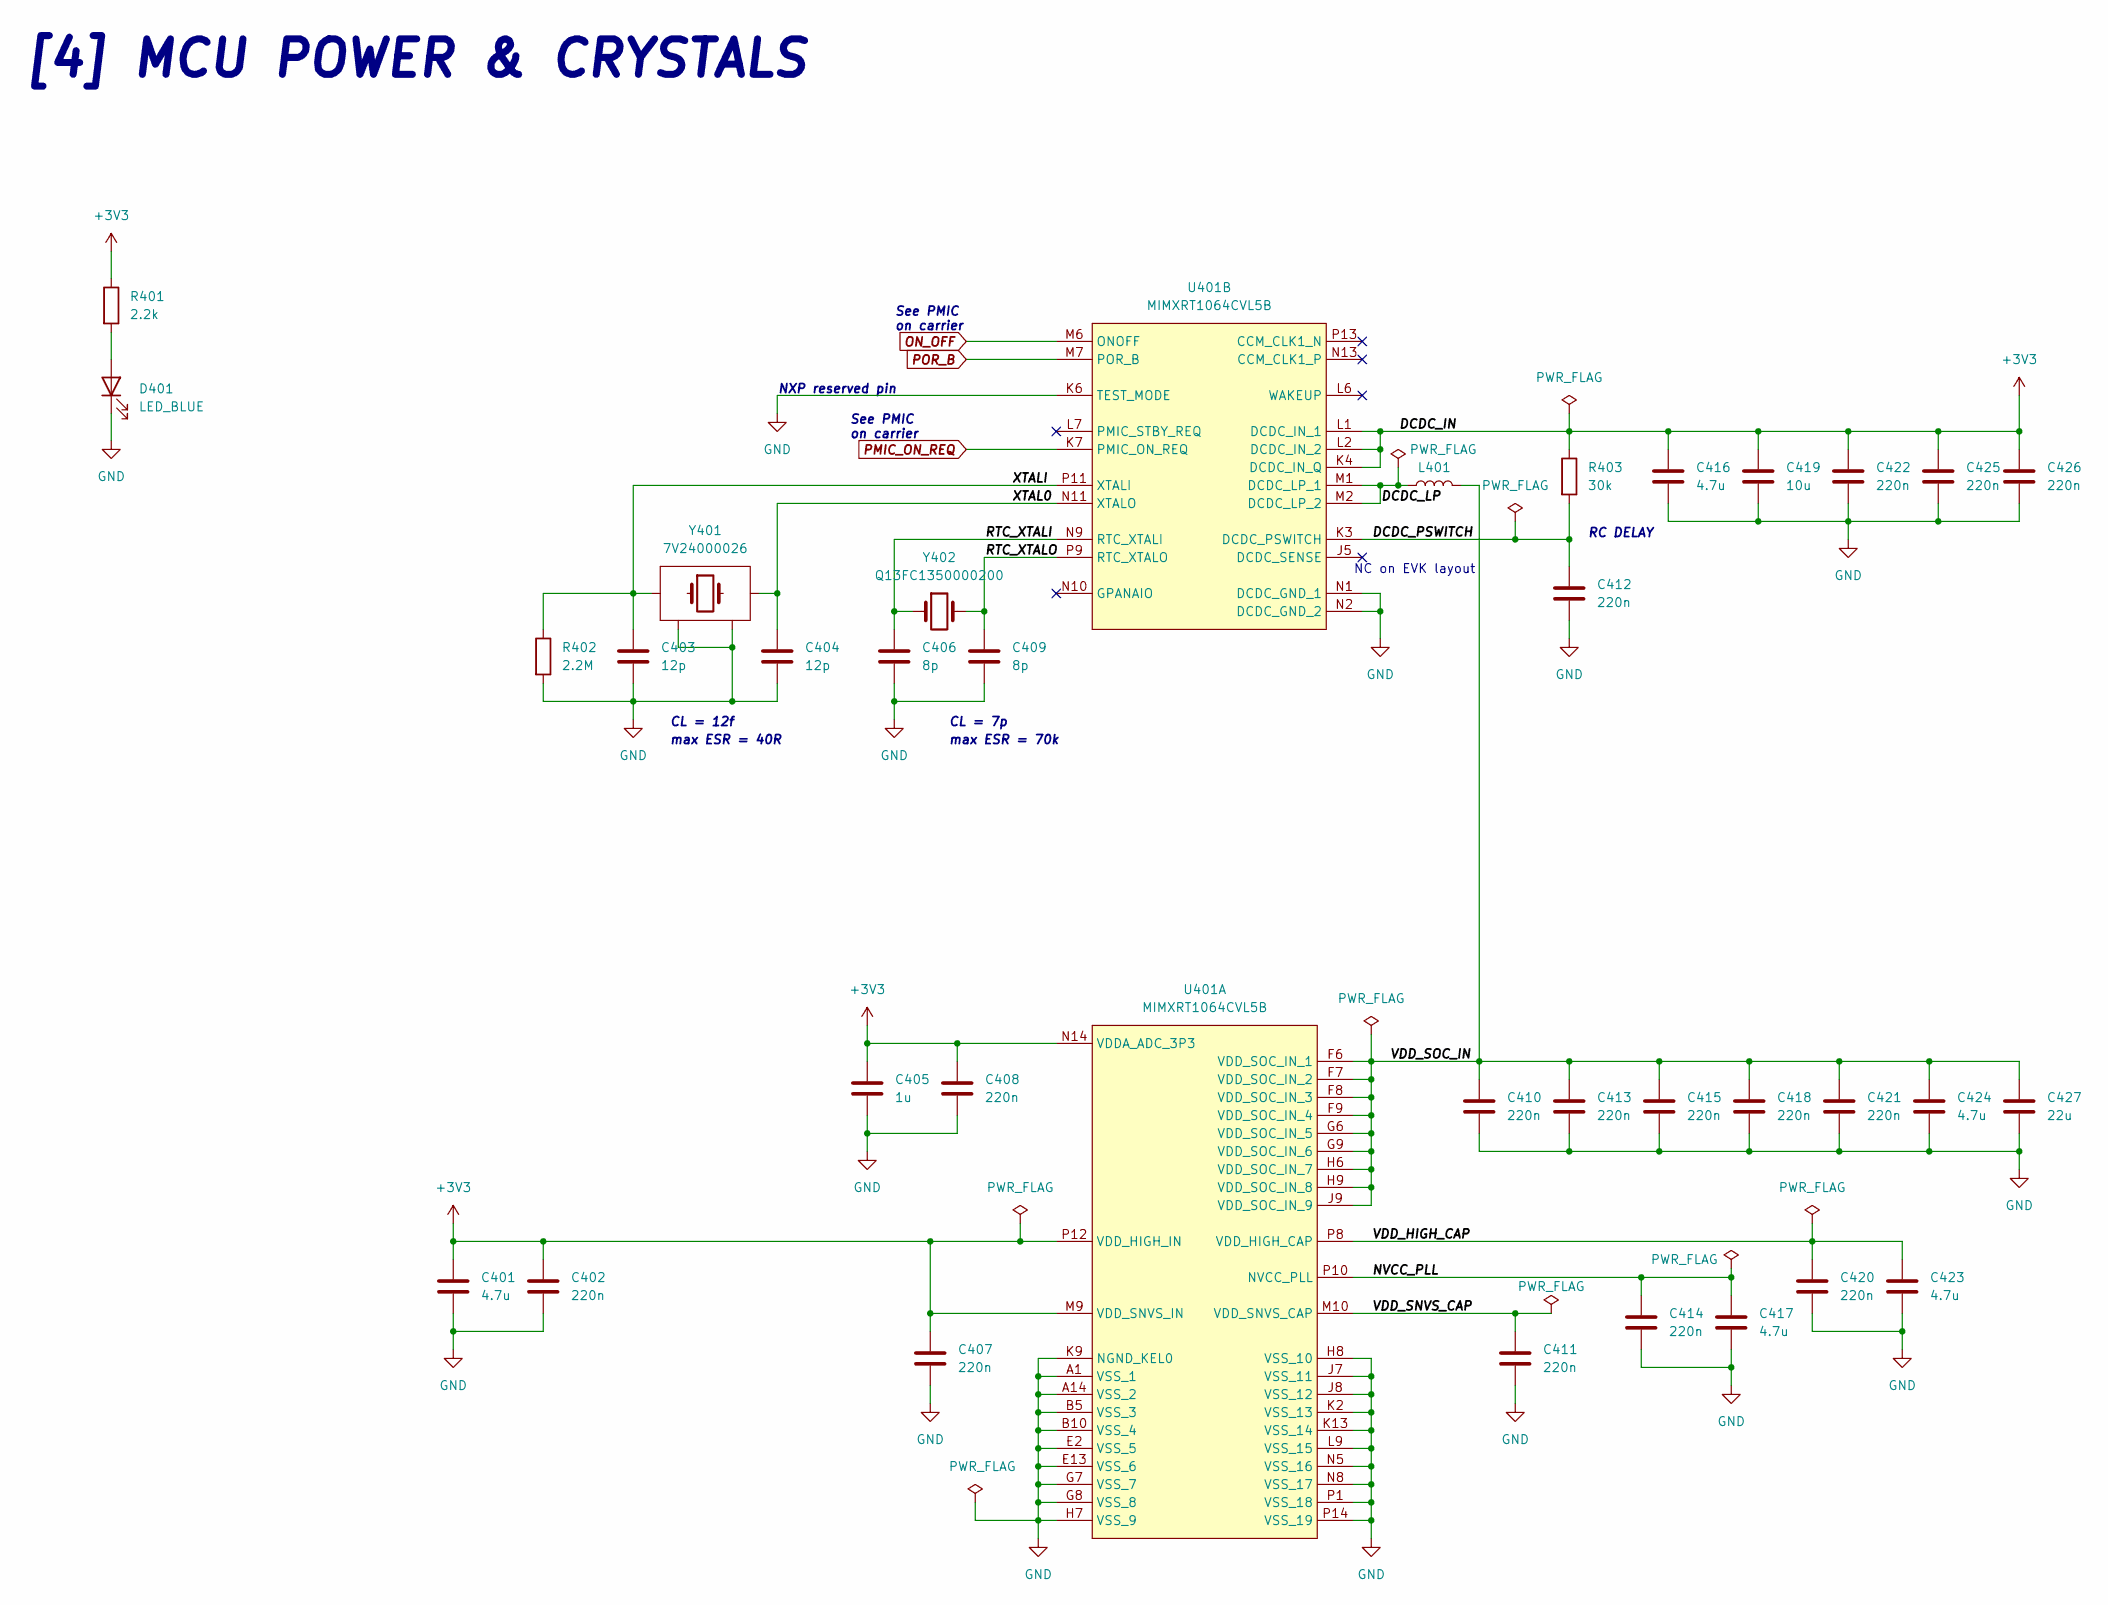
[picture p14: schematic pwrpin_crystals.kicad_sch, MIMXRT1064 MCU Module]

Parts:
C401, C416, C417, C423, C424: 4.7u; 0402_CL05A475MP5NRNC
C402, C407, C408, C410, C411, C412, C413, C414, C415, C418, C420, C421, C422, C425, C426: 220n; 0402_CL05B224KO5NNNC
C403, C404: 12p; CL10C120JB81PNC
C405: 1u; 0402_CL05A105KA5NQNC
C406, C409: 8p; CL10C080DB81PNC
C419: 10u; 0603_CL10A106KP8NNNC
C427: 22u; 0603_CL10A226MQ8NRNC
D401: LED_BLUE; 19-218_BHC-ZL1M2QY_3T
L401: VLS4012ET-4R7M
R401: 2.2k; 0603WAF2201T5E
R402: 2.2M; 0402WGJ0225TCE
R403: 30k; AF0402FR-0730KL
U401: MIMXRT1064CVL5B
Y401: 7V24000026
Y402: Q13FC1350000200

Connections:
+3V3: C401.1, C402.1, C405.1, C407.1, C408.1, C416.1, C419.1, C422.1, C425.1, C426.1, R401.1, R403.1, U401.K4 (DCDC_IN_Q), U401.L1 (DCDC_IN_1), U401.L2 (DCDC_IN_2), U401.M9 (VDD_SNVS_IN), U401.N14 (VDDA_ADC_3P3), U401.P12 (VDD_HIGH_IN); also elsewhere on the board
/MCU POWER & CRYSTALS/DCDC_LP: L401.1, U401.M1 (DCDC_LP_1), U401.M2 (DCDC_LP_2)
/MCU POWER & CRYSTALS/DCDC_PSWITCH: C412.1, R403.2, U401.K3 (DCDC_PSWITCH)
/MCU POWER & CRYSTALS/NVCC_PLL: C414.1, C417.1, U401.P10 (NVCC_PLL)
/MCU POWER & CRYSTALS/RTC_XTALI: C406.1, U401.N9 (RTC_XTALI), Y402.1
/MCU POWER & CRYSTALS/RTC_XTALO: C409.1, U401.P9 (RTC_XTALO), Y402.2
/MCU POWER & CRYSTALS/VDD_HIGH_CAP: C420.1, C423.1, U401.P8 (VDD_HIGH_CAP)
/MCU POWER & CRYSTALS/VDD_SNVS_CAP: C411.1, U401.M10 (VDD_SNVS_CAP)
/MCU POWER & CRYSTALS/VDD_SOC_IN: C410.1, C413.1, C415.1, C418.1, C421.1, C424.1, C427.1, L401.2, U401.F6 (VDD_SOC_IN_1), U401.F7 (VDD_SOC_IN_2), U401.F8 (VDD_SOC_IN_3), U401.F9 (VDD_SOC_IN_4), U401.G6 (VDD_SOC_IN_5), U401.G9 (VDD_SOC_IN_6), U401.H6 (VDD_SOC_IN_7), U401.H9 (VDD_SOC_IN_8), U401.J9 (VDD_SOC_IN_9)
/MCU POWER & CRYSTALS/XTAL0: C404.1, U401.N11 (XTALO), Y401.3
/MCU POWER & CRYSTALS/XTALI: C403.1, R402.1, U401.P11 (XTALI), Y401.1
GND: C401.2, C402.2, C403.2, C404.2, C405.2, C406.2, C407.2, C408.2, C409.2, C410.2, C411.2, C412.2, C413.2, C414.2, C415.2, C416.2, C417.2, C418.2, C419.2, C420.2, C421.2, C422.2, C423.2, C424.2, C425.2, C426.2, C427.2, D401.1 (K), R402.2, U401.A1 (VSS_1), U401.A14 (VSS_2), U401.B5 (VSS_3), U401.B10 (VSS_4), U401.E2 (VSS_5), U401.E13 (VSS_6), U401.G7 (VSS_7), U401.G8 (VSS_8), U401.H7 (VSS_9), U401.H8 (VSS_10), U401.J7 (VSS_11), U401.J8 (VSS_12), U401.K2 (VSS_13), U401.K6 (TEST_MODE), U401.K9 (NGND_KEL0), U401.K13 (VSS_14), U401.L9 (VSS_15), U401.N1 (DCDC_GND_1), U401.N2 (DCDC_GND_2), U401.N5 (VSS_16), U401.N8 (VSS_17), U401.P1 (VSS_18), U401.P14 (VSS_19), Y401.2 (GND), Y401.4 (GND); also elsewhere on the board
unnamed: D401.2 (A), R401.2
ON_OFF: U401.M6 (ONOFF); also elsewhere on the board
PMIC_ON_REQ: U401.K7 (PMIC_ON_REQ); also elsewhere on the board
POR_B: U401.M7 (POR_B); also elsewhere on the board

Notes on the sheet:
RC DELAY
NC on EVK layout
[4] MCU POWER & CRYSTALS
See PMIC on carrier
CL = 7p
max ESR = 70k
CL = 12f
NXP reserved pin
max ESR = 40R

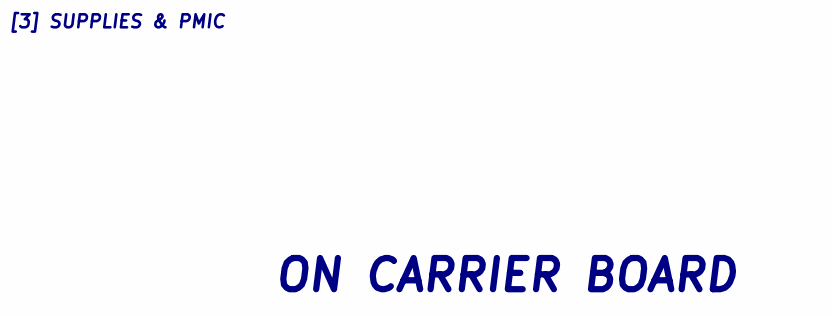
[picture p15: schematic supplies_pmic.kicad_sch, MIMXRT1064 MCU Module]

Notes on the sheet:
[3] SUPPLIES & PMIC
ON CARRIER BOARD

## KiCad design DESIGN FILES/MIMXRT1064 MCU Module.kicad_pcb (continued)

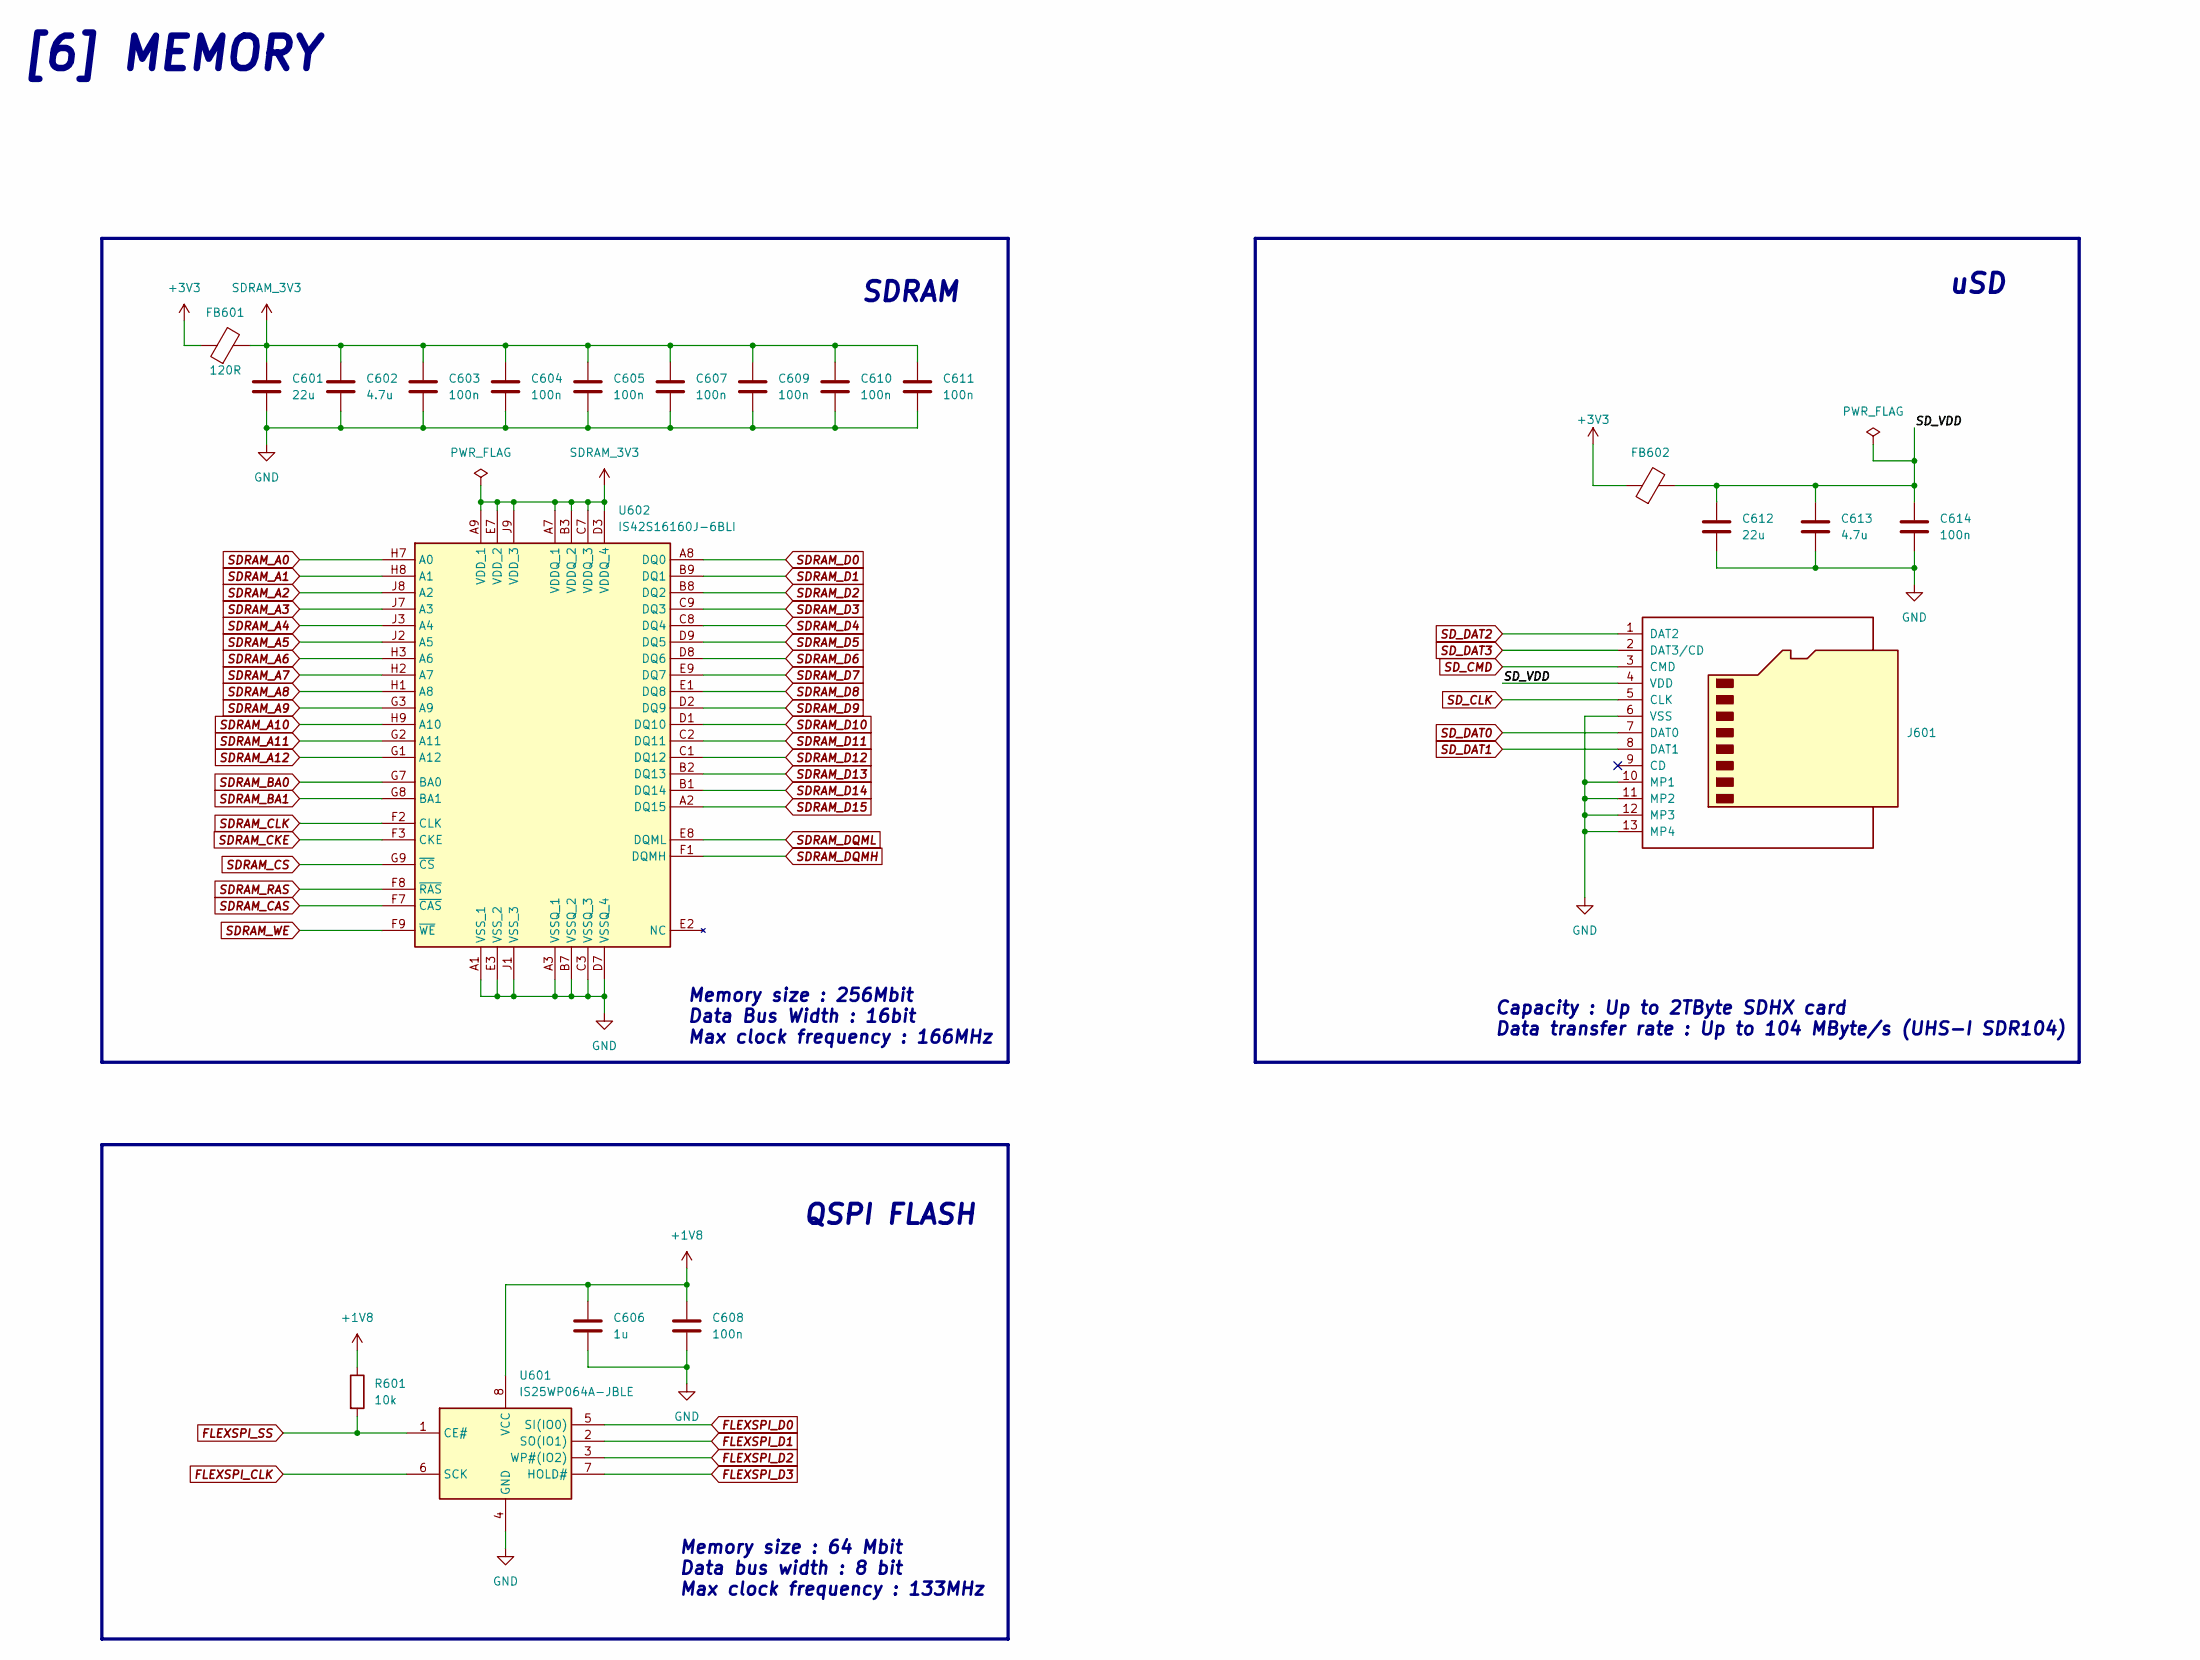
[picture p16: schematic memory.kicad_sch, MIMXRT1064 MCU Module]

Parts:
C601, C612: 22u; 0603_CL10A226MQ8NRNC
C602, C613: 4.7u; 0402_CL05A475MP5NRNC
C603, C604, C605, C607, C608, C609, C610, C611, C614: 100n; 0402_CL05B104KB54PNC
C606: 1u; 0402_CL05A105KA5NQNC
FB601: 120R; 0603_BLM18AG121SN1D
FB602: UPZ1608U601-1R3TF; UPZ1608U601-1R3TF_0603
J601: TF-15x15; TF-15x15_smd
R601: 10k; 0402WGF1002TCE
U601: IS25WP064A-JBLE; Manufacturer_Part_Number IS25WP064A-JBLE; Mouser Part Number 870-IS25WP064A-JBLE
U602: IS42S16160J-6BLI; Manufacturer_Part_Number IS42S16160J-6BLI; Mouser Part Number 870-42S16160J6BLI

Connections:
+1V8: C606.1, C608.1, R601.1, U601.8 (VCC); also elsewhere on the board
+3V3: FB601.1, FB602.1; also elsewhere on the board
/MEMORY /SD_VDD: C612.1, C613.1, C614.1, FB602.2, J601.4 (VDD)
FLEXSPI_CLK: U601.6 (SCK); also elsewhere on the board
FLEXSPI_D0: U601.5 (SI(IO0)); also elsewhere on the board
FLEXSPI_D1: U601.2 (SO(IO1)); also elsewhere on the board
FLEXSPI_D2: U601.3 (WP#(IO2)); also elsewhere on the board
FLEXSPI_D3: U601.7 (HOLD#); also elsewhere on the board
FLEXSPI_SS: R601.2, U601.1 (CE#); also elsewhere on the board
GND: C601.2, C602.2, C603.2, C604.2, C605.2, C606.2, C607.2, C608.2, C609.2, C610.2, C611.2, C612.2, C613.2, C614.2, J601.6 (VSS), J601.10 (MP1), J601.11 (MP2), J601.12 (MP3), J601.13 (MP4), U601.4 (GND), U602.A1 (VSS_1), U602.A3 (VSSQ_1), U602.B7 (VSSQ_2), U602.C3 (VSSQ_3), U602.D7 (VSSQ_4), U602.E3 (VSS_2), U602.J1 (VSS_3); also elsewhere on the board
SDRAM_3V3: C601.1, C602.1, C603.1, C604.1, C605.1, C607.1, C609.1, C610.1, C611.1, FB601.2, U602.A7 (VDDQ_1), U602.A9 (VDD_1), U602.B3 (VDDQ_2), U602.C7 (VDDQ_3), U602.D3 (VDDQ_4), U602.E7 (VDD_2), U602.J9 (VDD_3)
SDRAM_A0: U602.H7 (A0); also elsewhere on the board
SDRAM_A1: U602.H8 (A1); also elsewhere on the board
SDRAM_A2: U602.J8 (A2); also elsewhere on the board
SDRAM_A3: U602.J7 (A3); also elsewhere on the board
SDRAM_A4: U602.J3 (A4); also elsewhere on the board
SDRAM_A5: U602.J2 (A5); also elsewhere on the board
SDRAM_A6: U602.H3 (A6); also elsewhere on the board
SDRAM_A7: U602.H2 (A7); also elsewhere on the board
SDRAM_A8: U602.H1 (A8); also elsewhere on the board
SDRAM_A9: U602.G3 (A9); also elsewhere on the board
SDRAM_A10: U602.H9 (A10); also elsewhere on the board
SDRAM_A11: U602.G2 (A11); also elsewhere on the board
SDRAM_A12: U602.G1 (A12); also elsewhere on the board
SDRAM_BA0: U602.G7 (BA0); also elsewhere on the board
SDRAM_BA1: U602.G8 (BA1); also elsewhere on the board
SDRAM_CAS: U602.F7 (~CAS); also elsewhere on the board
SDRAM_CKE: U602.F3 (CKE); also elsewhere on the board
SDRAM_CLK: U602.F2 (CLK); also elsewhere on the board
SDRAM_CS: U602.G9 (~CS); also elsewhere on the board
SDRAM_D0: U602.A8 (DQ0); also elsewhere on the board
SDRAM_D1: U602.B9 (DQ1); also elsewhere on the board
SDRAM_D2: U602.B8 (DQ2); also elsewhere on the board
SDRAM_D3: U602.C9 (DQ3); also elsewhere on the board
SDRAM_D4: U602.C8 (DQ4); also elsewhere on the board
SDRAM_D5: U602.D9 (DQ5); also elsewhere on the board
SDRAM_D6: U602.D8 (DQ6); also elsewhere on the board
SDRAM_D7: U602.E9 (DQ7); also elsewhere on the board
SDRAM_D8: U602.E1 (DQ8); also elsewhere on the board
SDRAM_D9: U602.D2 (DQ9); also elsewhere on the board
SDRAM_D10: U602.D1 (DQ10); also elsewhere on the board
SDRAM_D11: U602.C2 (DQ11); also elsewhere on the board
SDRAM_D12: U602.C1 (DQ12); also elsewhere on the board
SDRAM_D13: U602.B2 (DQ13); also elsewhere on the board
SDRAM_D14: U602.B1 (DQ14); also elsewhere on the board
SDRAM_D15: U602.A2 (DQ15); also elsewhere on the board
SDRAM_DQMH: U602.F1 (DQMH); also elsewhere on the board
SDRAM_DQML: U602.E8 (DQML); also elsewhere on the board
SDRAM_RAS: U602.F8 (~RAS); also elsewhere on the board
SDRAM_WE: U602.F9 (~WE); also elsewhere on the board
SD_CLK: J601.5 (CLK); also elsewhere on the board
SD_CMD: J601.3 (CMD); also elsewhere on the board
SD_DAT0: J601.7 (DAT0); also elsewhere on the board
SD_DAT1: J601.8 (DAT1); also elsewhere on the board
SD_DAT2: J601.1 (DAT2); also elsewhere on the board
SD_DAT3: J601.2 (DAT3/CD); also elsewhere on the board

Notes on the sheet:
QSPI FLASH
Capacity : Up to 2TByte SDHX card Data transfer rate : Up to 104 MByte/s (UHS-I SDR104)
[6] MEMORY
SDRAM
uSD
Memory size : 256Mbit Data Bus Width : 16bit Max clock frequency : 166MHz
Memory size : 64 Mbit Data bus width : 8 bit Max clock frequency : 133MHz

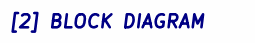
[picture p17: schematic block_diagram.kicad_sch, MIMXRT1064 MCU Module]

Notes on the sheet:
[2] BLOCK DIAGRAM

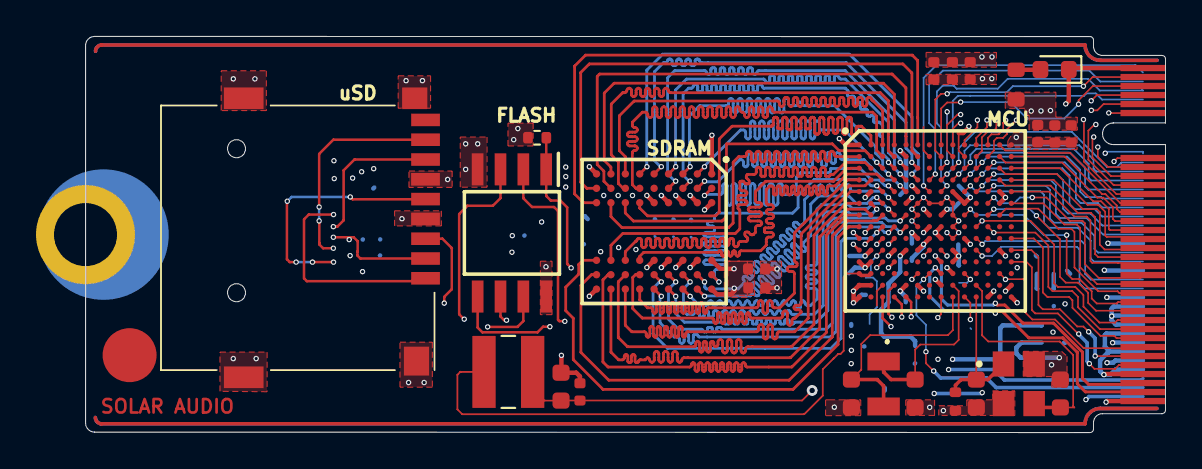
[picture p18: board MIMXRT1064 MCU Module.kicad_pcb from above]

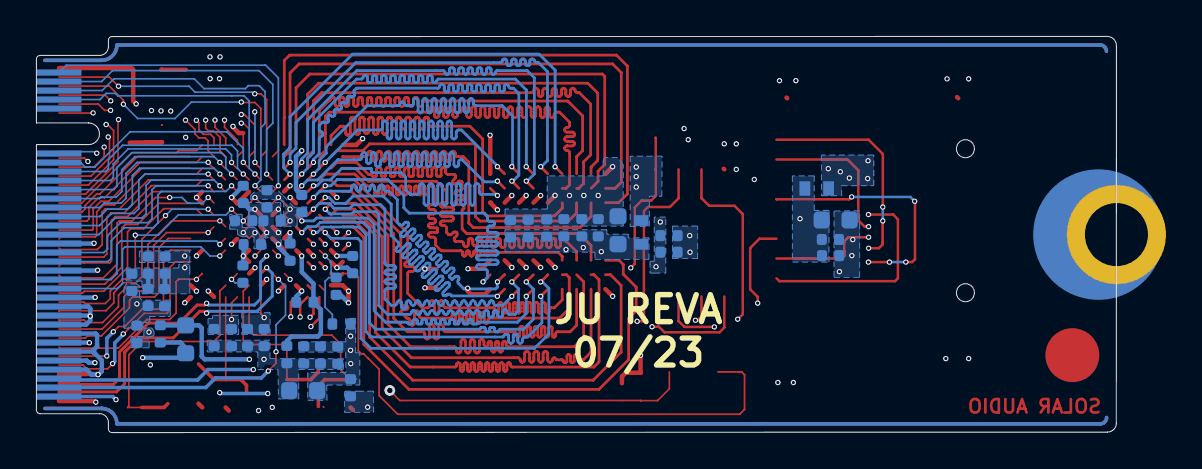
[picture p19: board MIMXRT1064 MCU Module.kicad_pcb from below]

Board: 6 copper layers, 60.0 x 22.0 mm, 70 parts (44 on the bottom side), 120 nets.

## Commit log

2023-05-18 Adding project files
    [MIMXRT1064 MCU Module.kicad_pcb, MIMXRT1064 MCU Module.kicad_sch, audio.kicad_sch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]
2023-05-18 Adding voltage monitor and manual reset circuit
    [MIMXRT1064 MCU Module.kicad_sch, audio.kicad_sch, mcu_pinout.kicad_sch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]
2023-05-18 Refactoring schematic
    [MIMXRT1064 MCU Module.kicad_sch, audio.kicad_sch, mcu_pinout.kicad_sch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]
2023-05-18 vcc check
    [MIMXRT1064 MCU Module.kicad_sch, mcu_power_crystals.kicad_sch, memory.kicad_sch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]
2023-05-18 Adding BOM and check sheets
    [MIMXRT1064 MCU Module - BOM.xlsx, MIMXRT1064 MCU Module - FOOTPRINTS CHECK.xlsx, MIMXRT1064 MCU Module - SYMBOL CHECK.xlsx]
2023-05-18 Adding component to BOM
    [MIMXRT1064 MCU Module - BOM.xlsx]
2023-05-18 schematic and lib edit
    [MIMXRT1064 MCU Module.kicad_sch, audio.kicad_sch, mcu_pinout.kicad_sch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]
2023-05-18 footprint checks
    [MIMXRT1064 MCU Module - BOM.xlsx, MIMXRT1064 MCU Module - FOOTPRINTS CHECK.xlsx]
2023-05-19 adding cells
    [MIMXRT1064 MCU Module - SYMBOL CHECK.xlsx]
2023-05-20 adding datasheet
    [MIMXRT1064 MCU Module.kicad_sch, supply_pmic.kicad_sch]
2023-05-20 Adding MPIT4030-680M-LF inductor to BOM
    [MIMXRT1064 MCU Module - BOM.xlsx]
2023-05-20 Adding TLV62569DBVR to BOM
    [MIMXRT1064 MCU Module - BOM.xlsx]
2023-05-20 Adding MPIT4030-680M-LF and TLV62569DBVR to check sheet
    [MIMXRT1064 MCU Module - FOOTPRINTS CHECK.xlsx, MIMXRT1064 MCU Module - SYMBOL CHECK.xlsx]
2023-05-20 Removing Sylergy DCDC from sheets
    [MIMXRT1064 MCU Module - BOM.xlsx, MIMXRT1064 MCU Module - FOOTPRINTS CHECK.xlsx, MIMXRT1064 MCU Module - SYMBOL CHECK.xlsx]
2023-05-20 removing SY8089AAAC from library
    [memory_usb.kicad_sch]
2023-05-20 symbol check MPIT4030-680M-LF
    [MIMXRT1064 MCU Module - SYMBOL CHECK.xlsx]
2023-05-20 TLV62569DBVR symbol check
    [MIMXRT1064 MCU Module - SYMBOL CHECK.xlsx, MIMXRT1064 MCU Module.kicad_sch, supply_pmic.kicad_sch]
2023-05-20 Update MIMXRT1064 MCU Module - FOOTPRINTS CHECK.xlsx
    [MIMXRT1064 MCU Module - FOOTPRINTS CHECK.xlsx]
2023-05-20 Removing audio codec from project
    [MIMXRT1064 MCU Module.kicad_sch, audio.kicad_sch]
2023-05-20 Adding power on led
    [MIMXRT1064 MCU Module - BOM.xlsx, MIMXRT1064 MCU Module - FOOTPRINTS CHECK.xlsx, MIMXRT1064 MCU Module - SYMBOL CHECK.xlsx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]
2023-05-20 schematic edit
    [MIMXRT1064 MCU Module.kicad_sch, mcu_pinout.kicad_sch, mcu_power_crystals.kicad_sch]
2023-05-20 crystals edit
    [MIMXRT1064 MCU Module - BOM.xlsx, MIMXRT1064 MCU Module - FOOTPRINTS CHECK.xlsx, MIMXRT1064 MCU Module - SYMBOL CHECK.xlsx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]
2023-05-22 schematic changes
    [MIMXRT1064 MCU Module.kicad_sch, gpio.kicad_sch, memory.kicad_sch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]
2023-05-23 sch changes
    [MIMXRT1064 MCU Module - BOM.xlsx, MIMXRT1064 MCU Module - FOOTPRINTS CHECK.xlsx, MIMXRT1064 MCU Module - SYMBOL CHECK.xlsx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]
2023-05-23 footprints and symbols check
    [MIMXRT1064 MCU Module - FOOTPRINTS CHECK.xlsx, MIMXRT1064 MCU Module - SYMBOL CHECK.xlsx, MIMXRT1064 MCU Module.kicad_sch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]
2023-05-23 Deleting datasheet
    [MIMXRT1064 MCU Module - BOM.xlsx]
2023-05-23 changes and adding schematic pdf
    [MIMXRT1064 MCU Module - BOM.xlsx, MIMXRT1064 MCU Module - FOOTPRINTS CHECK.xlsx, MIMXRT1064 MCU Module - SYMBOL CHECK.xlsx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]
2023-05-23 Update MIMXRT1064 MCU Module - BOM.xlsx
    [MIMXRT1064 MCU Module - BOM.xlsx]
